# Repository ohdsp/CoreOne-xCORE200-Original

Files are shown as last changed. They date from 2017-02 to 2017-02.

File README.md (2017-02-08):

# [Open Hardware DSP Platform](http://www.ohdsp.org)
## CoreOne
### Revision 1.0

---
# README
### Disclaimer
Copyright Paul Janicki 2017

Licensed under the TAPR Open Hardware License (www.tapr.org/OHL)

This documentation is distributed WITHOUT ANY EXPRESS OR IMPLIED WARRANTY, INCLUDING OF MERCHANTABILITY, SATISFACTORY QUALITY AND FITNESS FOR A PARTICULAR PURPOSE.

### What is this repository?

**Quick summary**

This is Open Hardware DSP Platform CoreOne Module. 

This is an XMOS 200 based DSP and microcontroller PCB design with USB, SPDIF, I2S/TDM, SPI, I2C, and Ethernet connectivity options.

This repository contains the KiCad design files, manufacturing Gerber/drill files, PDF/drawing files, and relevant documenation for this board.

### What is the project folder structure?
Most folder names are self explanatory. Starting from the top level: \
*CoreOne*
+ *Bill of Materials*  - This contains the bill of materials in CVS, LibreOffice Calc and XML formats
+ *Calculations*  - This contains calculations performed using SMath Studio 
+ *Drawings*  - This contains PDF and SVG outputs of schematic and PCB files
+ *Gerbers* - This contains the PCB Gerbers and drill drawings for manufacture, there is also a zip file ready to send to most manufacturers
+ *KiCad* - This contains the original KiCad schematic and PCB design files
+ *Pick and Place* - This contains the pick and place file for automated placement of PCB components

### How do I get set up?

**Summary of set up**

1. Set your self up a directory on a local disk, something simple will make life easier (eg C:\Electronics on Windows as used here), but anywhere will do just fine.
2. Download the Kicad-Libs from [https://github.com/ohdsp/KiCad-Libs](https://github.com/ohdsp/KiCad-Libs) and place in C:\Electronics\Kicad-Libs (or your chosen folder) 
3. Create a OHDSP subdirectory in C:\Electronics (so C:\Electronics\OHDSP)
3. Download this project to C:\Electronics\OHDSP\CoreOne
4. Fire up Kicad
5. Open the main project file C:\Electronics\OHDSP\CoreOne\KiCad\CoreOne.pro
6. (Optional) Setup Pcbnew component library as below.
7. Do as you wish with the project, just keep it under TAPR Open Hardware License

Make sure your git setup doesn't exclude files used in the project (like .LIB files) or things may go wrong down the line.

**KiCad Library Configuration**

Note that you need to setup a Pcbnew library, but the eeschema libraries should work without any changes if you followed the instructions above.

To setup Pcbnew libraries:

In Pcbnew go to Preferences -> Footprint Libraries Manager. Under Global Libraries tab in the top list check if there is a nickname "MyKiCadLibs-Footprints" (usually at the end of the list). If there is but it points to the wrong place then change the Library Path to point to MyKiCadLibs-Footprints (eg C:\Electronics\KiCad-Libs\MyKiCadLibs-Footprints.pretty) folder for your setup. If this is missing you can use "Append with Wizard", choose "Files on my computer", click next, browse to library location (eg C:\Electronics\KiCad-Libs\MyKiCadLibs-Footprints.pretty) and select the folder MyKiCadLibs-Footprints.pretty, click next, check the Status column states OK and the Format is KiCad (if not re-download the library) and click next, then select "To global library configuration..." and click Finish.

To setup eeschema component libraries:
Either from KiCad project window go to Tools -> Run Library Editor OR under eeschema, go to Tools -> Library Editor. Then Preferences -> Component Libraries.

The top section "Component Library Files" should ideally contain only two libraries, the "power" library that ships with KiCad and "MyKiCadLibs-Lib" available from above. To setup MyKiCadLibs-Lib as a relative path under the "User defined search path" click add. Browse to the location of KiCad-Libs you download above (eg C:\Electronics\KiCad-Libs) and click "Select Folder". Say yes to add a relative path. Under component library files click add, browse to the KiCad-libs again (eg C:\Electronics\KiCad-Libs), select file "MyKiCadLibs-Lib.lib" and click open. MyKiCadLibs-lib should appear in the component library list with no path as it will be using the user defined search path set in the box below.

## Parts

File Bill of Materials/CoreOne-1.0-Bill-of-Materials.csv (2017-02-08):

Reference | Quantity | Footprint | Value | Voltage | Type | Description | Tolerance | Size | Power | Current
C103 C105 C107 C218 C220 C221 C223 C305 C504 C644 C806 C807 C820 C858 C859 | 15 | SMD-0805 | 22u | '10V | 'X5R | 'Ceramic capacitor | '20% | '0805 | ' | '
C104 C106 C108 C203 C205 C206 C207 C208 C212 C224 C226 C231 C304 C306 C311 C312 C313 C315 C316 C404 C505 C508 C510 C512 C615 C617 C638 C641 C647 C653 C656 C703 C706 C707 C808 C852 C860 C861 | 38 | SMD-0805 | 100n | '50V | 'X7R | 'Ceramic capacitor | '10% | '0805 | ' | '
C201 C210 | 2 | CAP-TH-D6.3mmP2.5mm | 220u | '16V | '2.5mm pitch, 6.3mm diameter | 'Aluminium electrolytic capacitor | ' | ' | ' | '
C209 C301 C501 C637 C701 C802 C803 C816 C854 C855 | 10 | SMD-0805 | 100p | '50V | 'C0G | 'Ceramic capacitor | '5% | '0805 | ' | '
C202 C204 C211 | 3 | SMD-0805 | 22u | '25V | 'X5R | 'Ceramic capacitor | '20% | '0805 | ' | '
C214 C216 C709 | 3 | SMD-0805 | N/F | '50V | 'X7R | 'Ceramic capacitor | '10% | '0805 | ' | '
C227 C229 C303 C503 C640 C804 C805 C818 C856 C857 | 10 | CAP-TH-D6.3mmP2.5mm | 220u | '10V | '2.5mm pitch, 6.3mm diameter | 'Low impedance aluminium electrolytic capacitor - Panasonic FC, FR or similar | ' | ' | ' | '
C302 C309 C310 C507 C509 C511 C619 C702 C853 | 9 | SMD-0805 | 10u | '10V | 'X5R | 'Ceramic capacitor | '20% | '0805 | ' | '
C502 C506 C601 C602 | 4 | SMD-0805 | 33p | '50V | 'NP0 | 'Ceramic capacitor | '5% | '0805 | ' | '
C609 C611 | 2 | SMD-0805 | 1u | '10V | 'X7R | 'Ceramic capacitor | '10% | '0805 | ' | '
C704 C705 C708 C851 | 4 | SMD-0805 | 10n | '50V | 'X7R | 'Ceramic capacitor | '10% | '0805 | ' | '
C810 C812 C814 | 3 | SMD-0603 | 1u | '10V | 'X7R | 'Ceramic capacitor | '10% | '0603 | ' | '
C811 C824 C832 C834 C840 C844 C846 C850 C867 | 9 | SMD-0603 | 10n | '50V | 'X7R | 'Ceramic capacitor | '10% | '0603 | ' | '
C809 C823 C831 C833 C839 C843 C845 C849 C862 C863 C864 C866 C870 C871 C873 C874 | 16 | SMD-0603 | 100n | '50V | 'X7R | 'Ceramic capacitor | '10% | '0603 | ' | '
CN301 CN302 CN501 | 3 | CONN_SIL_2_1MM | COAX | ' | ' | '1x2 2.54mm pitch pin header - use with 75Ohm coax | ' | ' | ' | '
CN401 | 1 | CONN-USB-B-61729-0010 | CONN-USB-B-61729 | ' | ' | 'USB B Connector - Amphenol 61729 Series - eg: 61729-0010 | ' | ' | ' | '
CN601 | 1 | CONN-RJ45-ARJC02-111xxxx | CONN_RJ45_ARJC02-111xxxx | ' | ' | 'Amphenol RJE48 series RJ45 connector with LED - eg: RJE48-188-1411 | ' | ' | ' | '
D201 | 1 | DIODE-SMA | B240A | ' | ' | 'B240A 2A 40V Schottky Rectifier - SMA (DO-214AC) | ' | ' | ' | '
D202 | 1 | SMD-1206 | Green LED 1206 | ' | ' | 'Green LED - SMD - Vf 1.8V to 2.2V | ' | '1206 | ' | '
D401 D402 D403 D404 D405 D406 D407 D408 | 8 | IC-SOT23 | BAV99 | ' | ' | 'Text description | ' | ' | ' | '
D601 D602 | 2 | DIODE-SOD-123 | SS14L | ' | ' | 'SS14L 1A 40V Schottky rectifier - Sub-SMA (SOD-123) | ' | ' | ' | '
FID201 FID202 FID203 | 3 | FID-1MM-3MM | MNT_HOLE | ' | ' | 'Fiducial | ' | ' | ' | '
JP301 | 1 | CONN_SIL_3_1MM | CONN_3x1 | ' | ' | '1x3 2.54mm pitch pin header | ' | ' | ' | '
L201 L301 L501 L604 L801 L802 L803 L804 L805 | 9 | SMD-0805 | 600R@100MHz | ' | ' | 'Ferrite bead, current rating 1A or higher, 600R@100MHz | ' | '0805 | ' | '=>1A
L202 | 1 | IND-TH-DR0608 | DR0608-332L | ' | ' | 'Coilcraft DR0608-332L DCR=0.012Ohm Isat=5.3A Irms=5.0A | ' | ' | ' | '2.7A
L204 | 1 | IND-TH-DR0608 | DR0608-153L | ' | ' | 'Coilcraft DR0608-153L DCR=0.052Ohm Isat=2.7A Irms=2.7A | ' | ' | ' | '2.7A
MNT201 MNT202 MNT203 MNT204 | 4 | MNT_HOLE_3.2mm | MNT_HOLE | ' | ' | 'Mounting hole | ' | ' | ' | '
P201 | 1 | CONN-2WAY-2.54mm-3.81mm-SPACING | CONN_2x1 | ' | ' | '2 way screw terminal, any 2.54mm to 3.81mm pitch part | ' | ' | ' | '
JP801 JP802 JP803 JP804 P202 P701 | 6 | CONN_SIL_2_1MM | CONN_2x1 | ' | ' | '1x2 2.54mm pitch pin header | ' | ' | ' | '
P402 P408 | 2 | CONN_DIL_2X04 | CONN_02X04 | ' | ' | '2x4 2.54mm pitch pin header | ' | ' | ' | '
P403 | 1 | CONN_DIL_2X10_BOX_1MM | CONN_02X10 | ' | ' | '2x10 2.54mm pitch box header | ' | ' | ' | '
P404 | 1 | CONN_DIL_2X4_BOX_1MM | CONN_02X04 | ' | ' | '2x4 2.54mm pitch box header | ' | ' | ' | '
P405 | 1 | CONN_DIL_2X6_BOX_1MM | CONN_02X06 | ' | ' | '2x6 2.54mm pitch box header | ' | ' | ' | '
P401 P406 P407 | 3 | CONN_DIL_2X5_BOX_1MM | CONN_02X05 | ' | ' | '2x5 2.54mm pitch box header | ' | ' | ' | '
R101 R102 R104 R106 R108 R208 R214 R413 R414 R416 R417 R418 R420 R421 R422 R427 R429 R713 R821 R822 R823 R824 R825 R826 R827 R828 R829 R830 R831 R862 R874 R875 R887 R888 R890 R891 R892 R893 | 38 | SMD-0805 | 0 | ' | ' | 'Thick or thin film resistor | '1% | '0805 | '100mW | '
R103 R105 R107 R109 R401 R402 R409 R410 R423 R424 R425 R426 R434 R435 R436 R438 R504 R506 R510 R515 R602 R620 R631 R633 R638 R642 R803 R804 | 28 | SMD-0805 | N/F | ' | ' | 'Thick or thin film resistor | '1% | '0805 | '100mW | '
R110 R111 R112 R113 R114 R115 R116 R117 R604 R605 R606 R607 R608 R609 R621 R863 R864 R869 R877 R878 R879 R880 R881 R883 R884 R885 R886 R889 | 28 | SMD-0805 | 33 | ' | ' | 'Thick or thin film resistor | '1% | '0805 | '100mW | '
R201 R204 R403 R404 R405 R406 R407 R408 R412 R415 R502 R511 R610 R611 R613 R619 R632 R634 R805 R806 R820 R843 | 22 | SMD-0805 | 1k | ' | ' | 'Thick or thin film resistor | '1% | '0805 | '100mW | '
R202 R209 | 2 | SMD-0805 | 10 | ' | ' | 'Thick or thin film resistor | '1% | '0805 | '100mW | '
R203 | 1 | SMD-0805 | 750 | ' | ' | 'Thick or thin film resistor | '1% | '0805 | '100mW | '
R205 R301 R501 R617 R702 R801 R802 R817 R865 R866 | 10 | SMD-0805 | 47 | ' | ' | 'Thick or thin film resistor | '1% | '0805 | '100mW | '
R206 | 1 | SMD-0805 | 8k25 | ' | ' | 'Thick or thin film resistor | '1% | '0805 | '100mW | '
R207 | 1 | SMD-0805 | 33k | ' | ' | 'Thick or thin film resistor | '1% | '0805 | '100mW | '
R212 | 1 | SMD-0805 | 36k | ' | ' | 'Thick or thin film resistor | '1% | '0805 | '100mW | '
R213 | 1 | SMD-0805 | 11k5 | ' | ' | 'Thick or thin film resistor | '1% | '0805 | '100mW | '
R215 | 1 | SMD-0805 | 220 | ' | ' | 'Thick or thin film resistor | '1% | '0805 | '100mW | '
R304 R305 R306 R307 R313 R430 R431 R432 | 8 | SMD-0805 | 75 | ' | ' | 'Thick or thin film resistor | '1% | '0805 | '100mW | '
R302 R308 R309 R612 R703 R844 | 6 | SMD-0805 | 10k | ' | ' | 'Thick or thin film resistor | '1% | '0805 | '100mW | '
R310 | 1 | SMD-0805 | 360 | ' | ' | 'Thick or thin film resistor | '1% | '0805 | '100mW | '
R311 R709 R710 R711 | 4 | SMD-0805 | 100 | ' | ' | 'Thick or thin film resistor | '1% | '0805 | '100mW | '
R312 | 1 | SMD-0805 | 91 | ' | ' | 'Thick or thin film resistor | '1% | '0805 | '100mW | '
R411 R701 | 2 | SMD-0805 | 1 | ' | ' | 'Thick or thin film resistor | '1% | '0805 | '100mW | '
R503 | 1 | SMD-0805 | 1Meg | ' | ' | 'Thick or thin film resistor | '1% | '0805 | '100mW | '
R507 R512 | 2 | SMD-0805 | 0R | ' | ' | 'Thick or thin film resistor | '1% | '0805 | '100mW | '
R505 R508 R509 R513 R516 | 5 | SMD-0805 | 33R | ' | ' | 'Thick or thin film resistor | '1% | '0805 | '100mW | '
R615 | 1 | SMD-0805 | 6K49 | ' | ' | 'Thick or thin film resistor | '1% | '0805 | '100mW | '
R623 R624 | 2 | SMD_MELF_0207 | 220 | ' | ' | 'MELF Resistor | '1% | 'MELF0207 | '400mW | '
R637 R641 | 2 | SMD-0805 | 4k7 | ' | ' | 'Thick or thin film resistor | '1% | '0805 | '100mW | '
R708 | 1 | SMD-0805 | 7k5 | ' | ' | 'Thick or thin film resistor | '1% | '0805 | '100mW | '
R704 R712 | 2 | SMD-0805 | 100k | ' | ' | 'Thick or thin film resistor | '1% | '0805 | '100mW | '
R818 R819 | 2 | SMD-0805 | 2k2 | ' | ' | 'Thick or thin film resistor | '1% | '0805 | '100mW | '
R876 | 1 | SMD-0805 | 43R2 | ' | ' | 'Thick or thin film resistor | '1% | '0805 | '100mW | '
SW701 | 1 | SW_TACT_SMD | SWITCH | ' | ' | '6mm x 6mm SMD tactile switch - e.g. TE FSM2JSMA | ' | ' | ' | '
TP401 TP402 TP403 TP404 TP405 TP406 TP407 TP408 TP411 TP412 TP413 TP414 TP415 TP416 | 14 | TP-TH-1mm | PIN
TP501 | 1 | TP-1mm | PIN
TP803 | 1 | TP-1mm | PIN | ' | ' | 'Text description | ' | ' | ' | '
U102 U103 U104 | 3 | IC-SC70-6 | NC7WZ16P6X
U201 U202 | 2 | IC_SOIC_8 | IC-REG-ST1S40IDR | ' | ' | 'ST ST1S31 SO8 3 A DC step-down switching regulator | ' | ' | ' | '
U301 | 1 | IC-SC70-6 | NC7WZ16P6X | ' | ' | 'UHS Dual Buffer | ' | ' | ' | '
U302 | 1 | IC_SPDIF_OPTO | IC-SPDIF-RX-OPTO | ' | ' | 'TOSLINK receiver e.g. CLIFF FC684205R | ' | ' | ' | '
U303 | 1 | IC_SPDIF_OPTO | IC-SPDIF-TX-OPTO | ' | ' | 'TOSLINK transmitter e.g. CLIFF FC684205T | ' | ' | ' | '
U304 | 1 | IC_SOIC_14 | 74HC04 | ' | ' | '74HC04 Hex Inverter - SOIC-14 | ' | ' | ' | '
U501 | 1 | IC-SC70-6 | NC7WZ04P6X | ' | ' | 'NC7WZ04 TinyLogic UHS Dual Inverter | ' | ' | ' | '
U502 | 1 | IC-MSOP-10 | CS2200-CP | ' | ' | 'Cirrus Logic CS2200-CP Fractional-N Frequency Synthesizer | ' | ' | ' | '
U503 | 1 | IC-MSOP-10 | CS2100-CP | ' | ' | 'Cirrus Logic CS2100-CP Fractional-N Frequency Synthesizer | ' | ' | ' | '
U601 | 1 | IC-LQFP48_7x7 | KSZ8081MLX | ' | ' | 'Microchip KSZ8081MLXCA LQFP-48 10Base-T/100Base-TX Ethernet PHY | ' | ' | ' | '
U701 | 1 | IC-SOT23-6 | TPS3808 | ' | ' | 'TI TPS3808 SOT-23 Reset Supervisor | ' | ' | ' | '
U801 | 1 | IC-TQ128-XMOS-HF | IC-uC-XE216-512-TQ128 | ' | ' | 'XMOS 200 XE216-512-TQ128 Microcontroller | ' | ' | ' | '
U802 | 1 | IC_SOIC_8 | IC-FLASH-SPI | ' | ' | 'SPI/Quad SPI Flash Memory - SOIC 8 - For use with XE-216-TQ128, XEF216-512-TQ128 has internal flash | ' | ' | ' | '
X501 | 1 | XTAL_HC49_TH | 24M000 | ' | ' | 'HC49 24.000MHz Crystal – 30ppm or better – 18pF | ' | ' | ' | '
X601 | 1 | XTAL_HC49_TH | 25M000 | ' | ' | 'HC49 25.000MHz Crystal – 50ppm or better – 18pF | ' | ' | ' | '

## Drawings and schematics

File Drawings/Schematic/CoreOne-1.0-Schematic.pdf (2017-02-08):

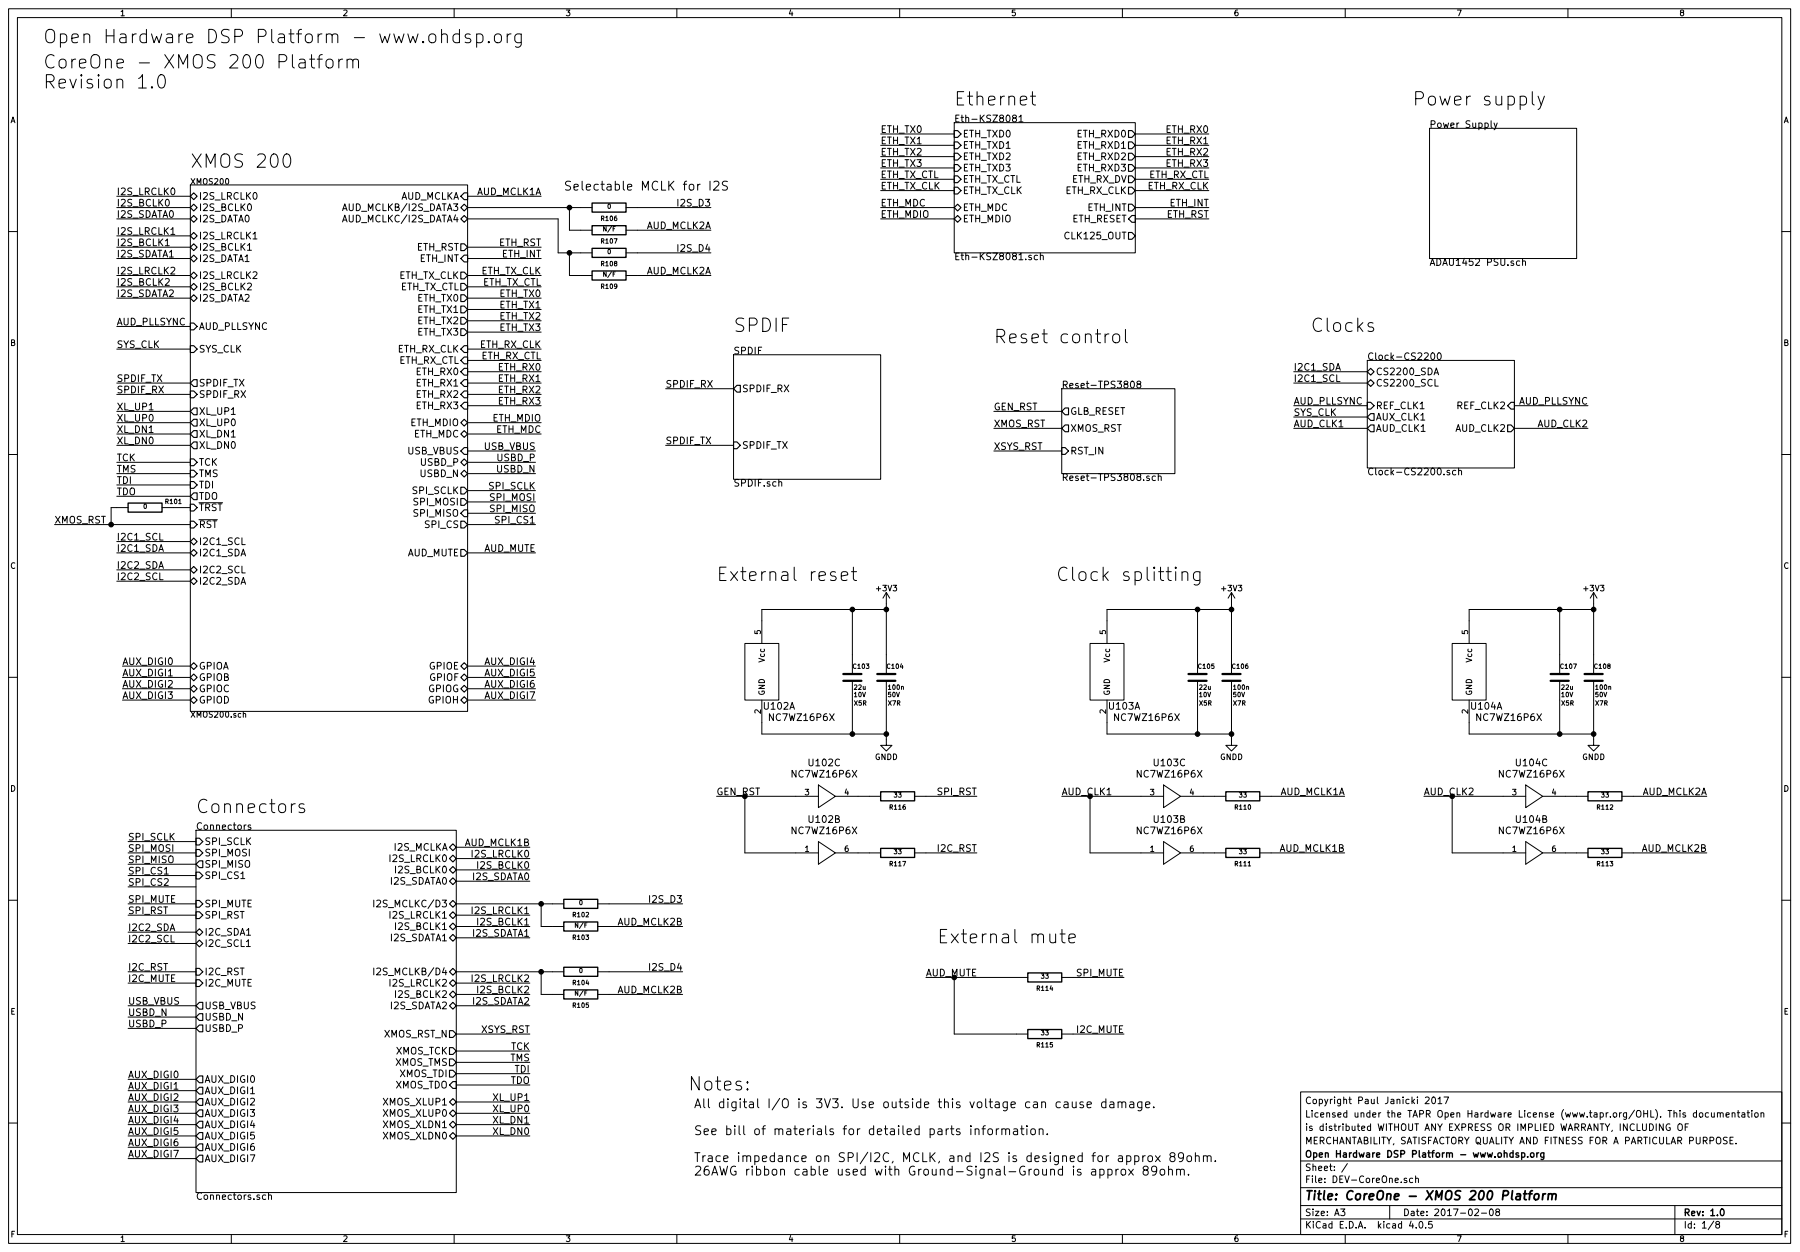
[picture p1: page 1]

Open Hardware DSP Platform - www.ohdsp.org
CoreOne - XMOS 200 Platform
Revision 1.0

ETH_TX1 | ETH_RX1
ETH_TX2 | ETH_RX2
ETH_TX3 | ETH_RX3
ETH_TX_CTL | | ETH_RX_CTL
ETH_TX_CLK | | ETH_RX_CLK

I2S_BCLK1
I2S_SDATA1 | ETH_INT

I2S_BCLK2 | ETH_TX_CTL
I2S_SDATA2

I2S_LRCLK1
I2S_SDATA1

I2C2_SCL

I2C_MUTE | | I2S_LRCLK2

I2S_BCLK2

Notes:
All digital I/O is 3V3. Use outside this voltage can cause damage.
See bill of materials for detailed parts information.
Trace impedance on SPI/I2C, MCLK, and I2S is designed for approx 89ohm.
26AWG ribbon cable used with Ground-Signal-Ground is approx 89ohm.

Copyright Paul Janicki 2017
Licensed under the TAPR Open Hardware License (www.tapr.org/OHL). This documentation
is distributed WITHOUT ANY EXPRESS OR IMPLIED WARRANTY, INCLUDING OF
MERCHANTABILITY, SATISFACTORY QUALITY AND FITNESS FOR A PARTICULAR PURPOSE.
File: DEV-CoreOne.sch Sheet: / Open Hardware DSP Platform - www.ohdsp.org

Id: 1/8 Title: CoreOne - XMOS 200 Platform

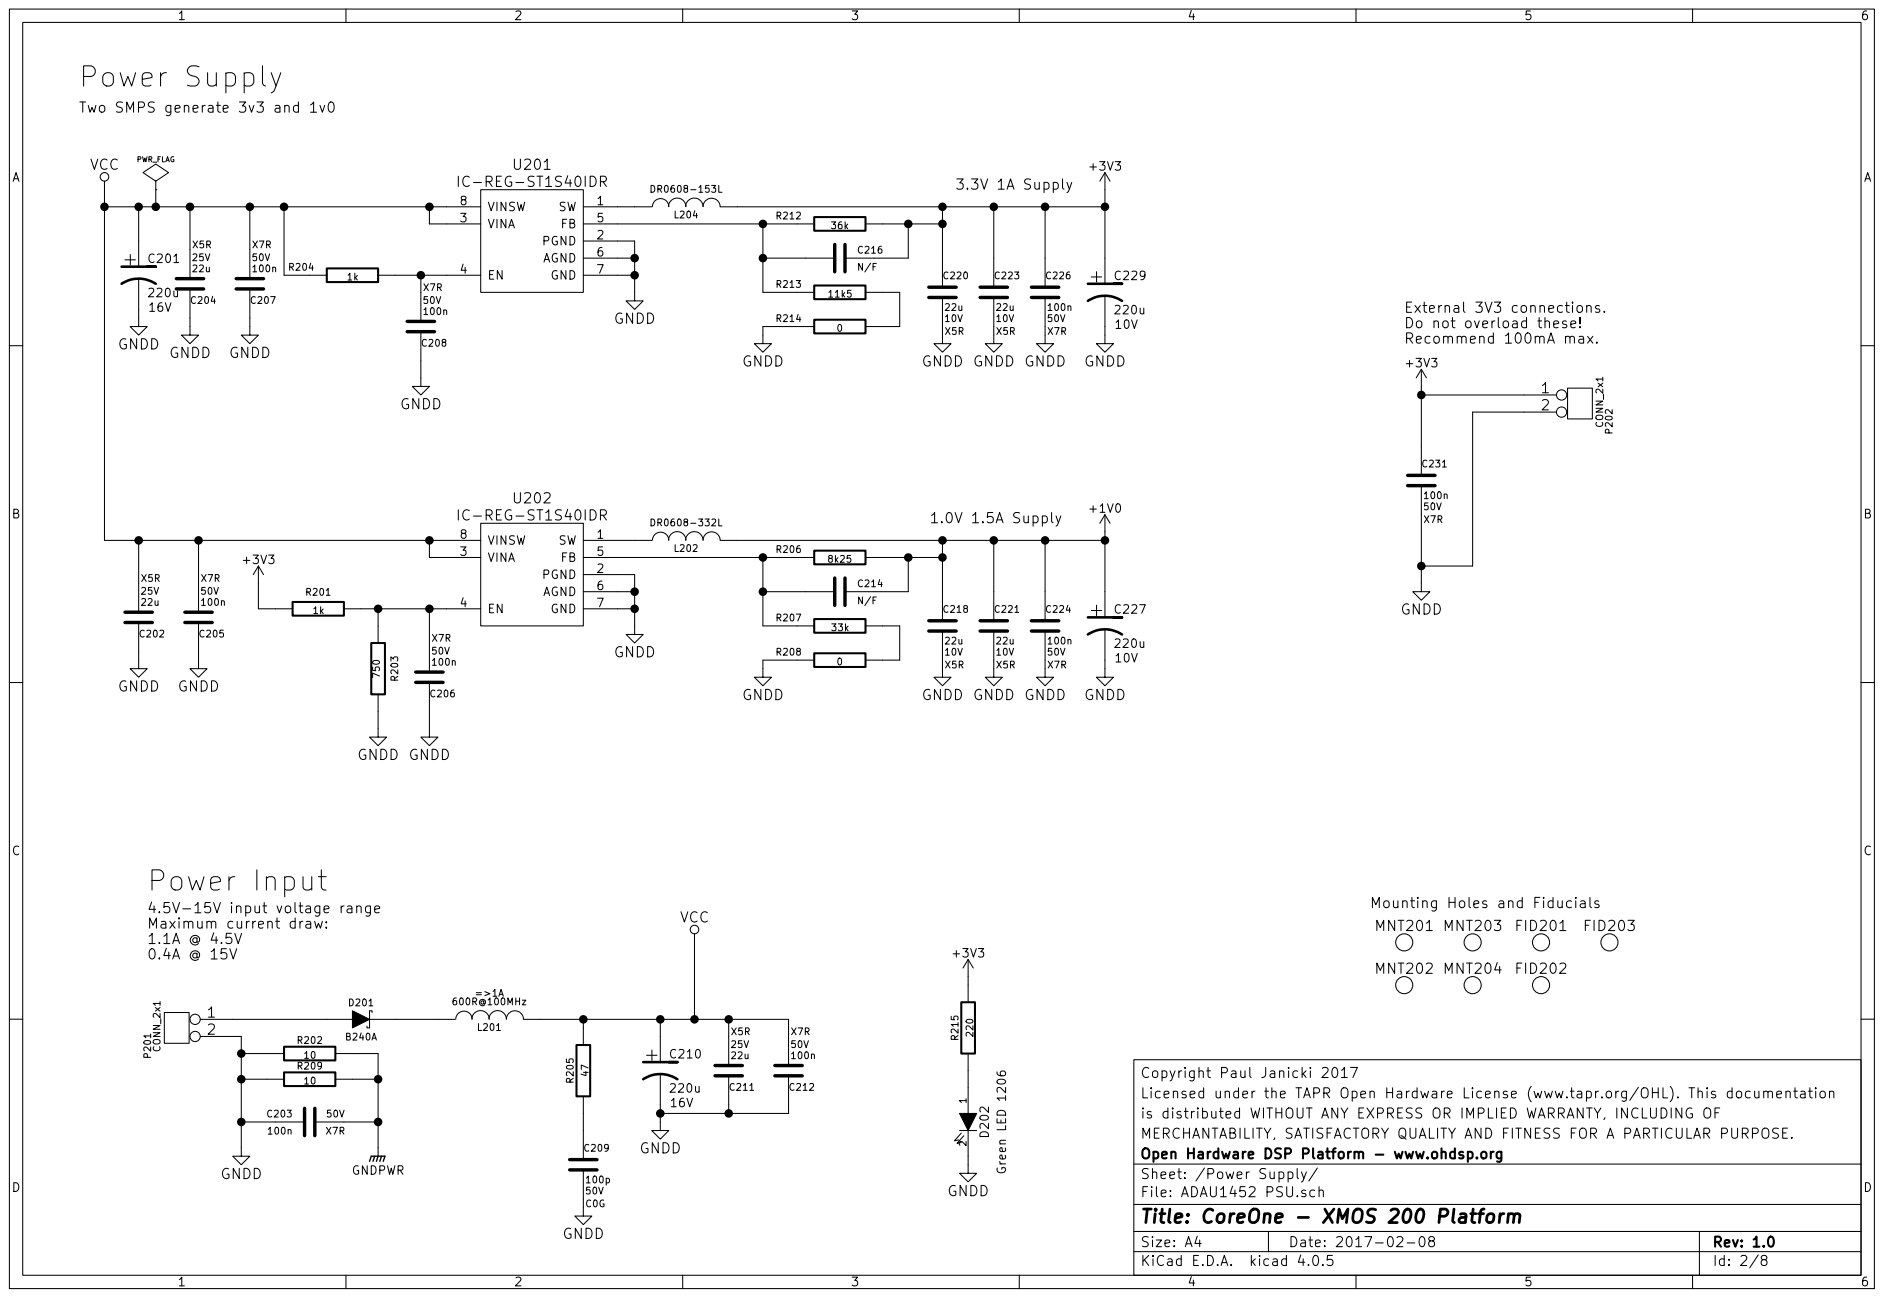
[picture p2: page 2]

Two SMPS generate 3v3 and 1v0

4.5V-15V input voltage range Maximum current draw: 1.1A @ 4.5V

Copyright Paul Janicki 2017
Licensed under the TAPR Open Hardware License (www.tapr.org/OHL). This documentation
is distributed WITHOUT ANY EXPRESS OR IMPLIED WARRANTY, INCLUDING OF
MERCHANTABILITY, SATISFACTORY QUALITY AND FITNESS FOR A PARTICULAR PURPOSE.
Open Hardware DSP Platform - www.ohdsp.org
File: ADAU1452 PSU.sch Sheet: /Power Supply/
Id: 2/8 Title: CoreOne - XMOS 200 Platform

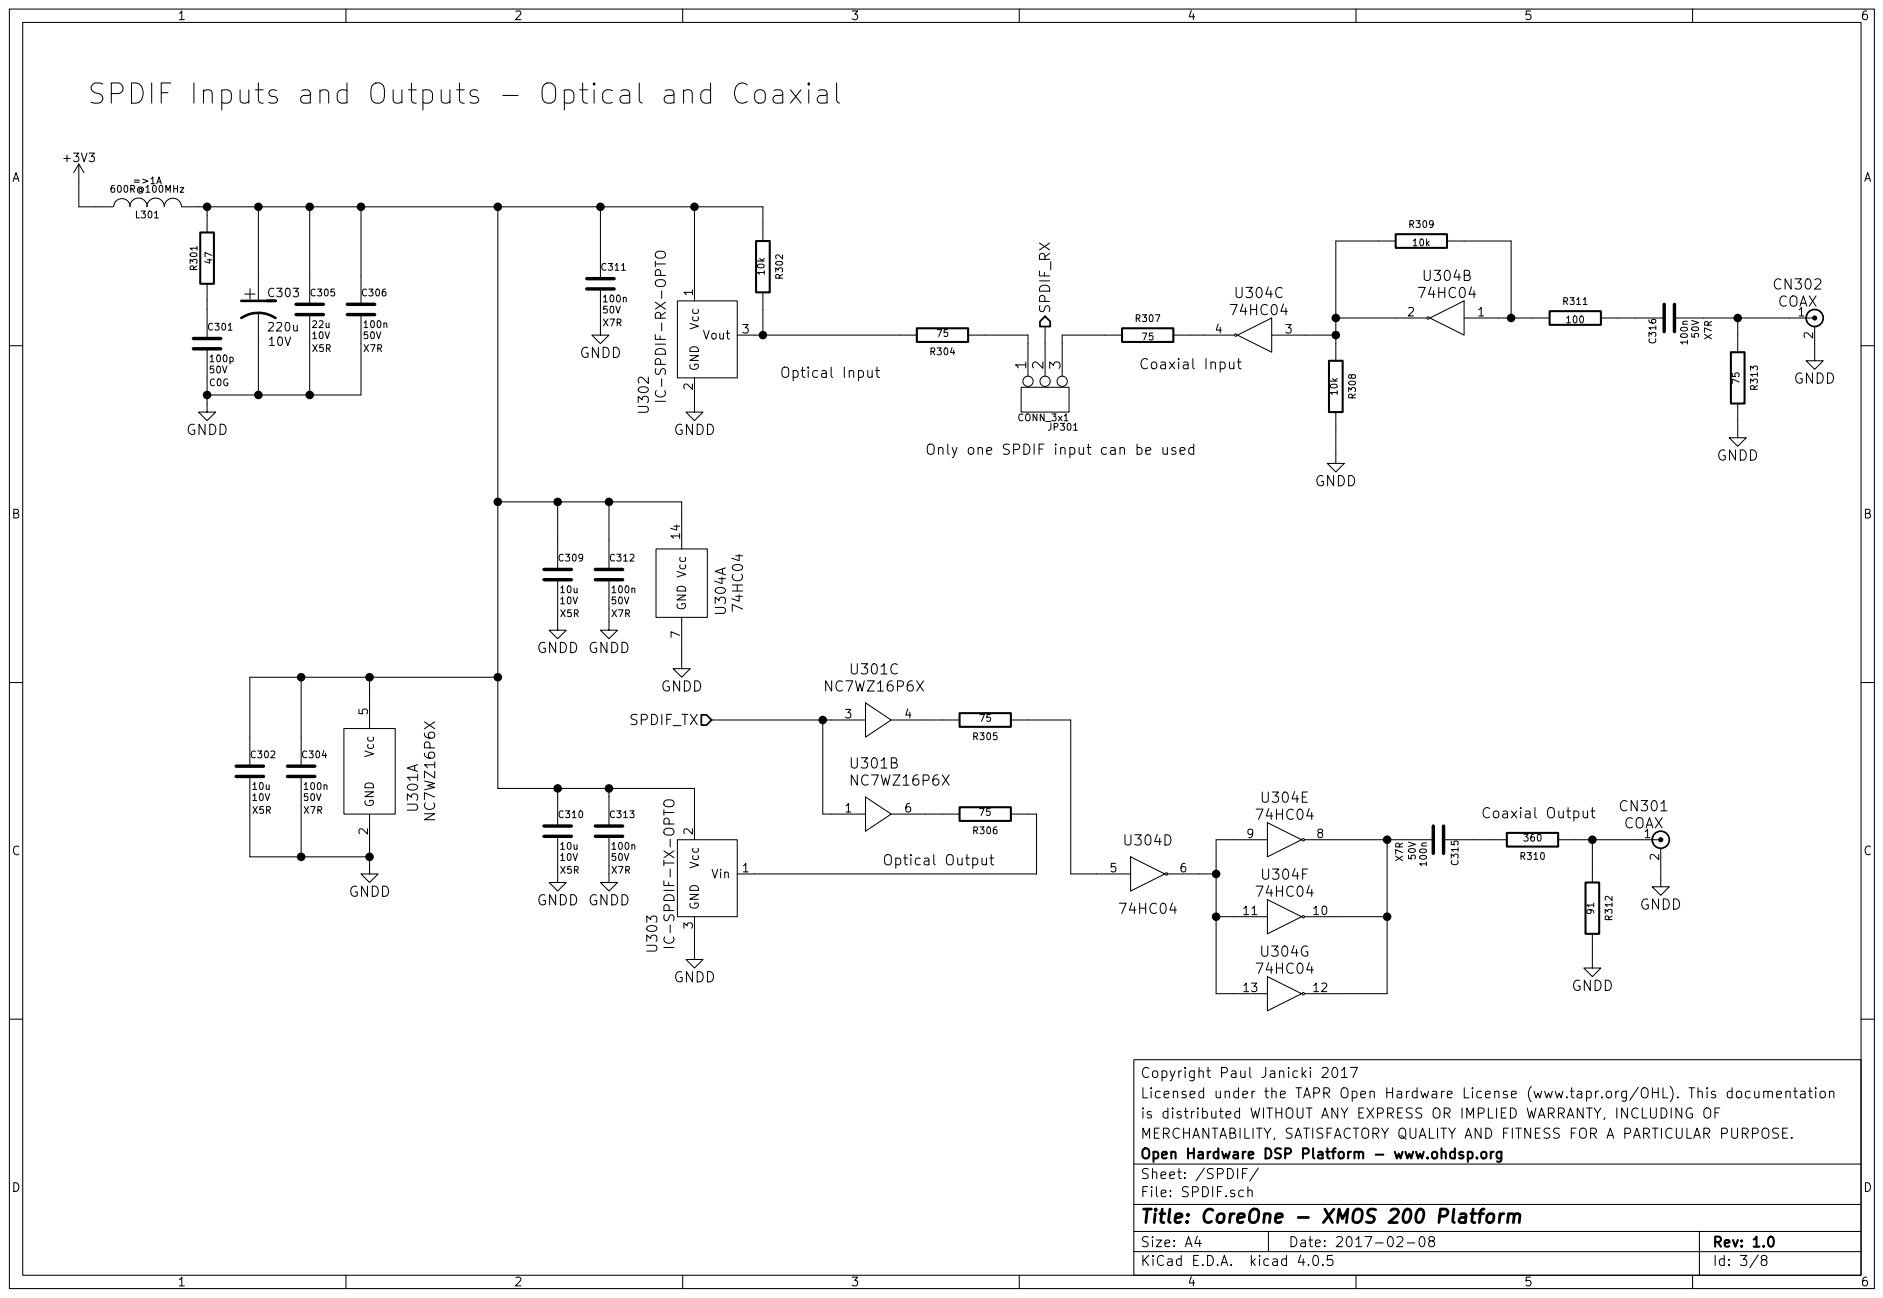
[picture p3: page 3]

SPDIF Inputs and Outputs - Optical and Coaxial Vcc 1 GND

2 Vout 3 U302IC-SPDIF-RX-OPTO

3 U303 IC-SPDIF-TX-OPTO

Copyright Paul Janicki 2017
Licensed under the TAPR Open Hardware License (www.tapr.org/OHL). This documentation
is distributed WITHOUT ANY EXPRESS OR IMPLIED WARRANTY, INCLUDING OF
MERCHANTABILITY, SATISFACTORY QUALITY AND FITNESS FOR A PARTICULAR PURPOSE.
File: SPDIF.sch Sheet: /SPDIF/ Open Hardware DSP Platform - www.ohdsp.org

Id: 3/8 Title: CoreOne - XMOS 200 Platform

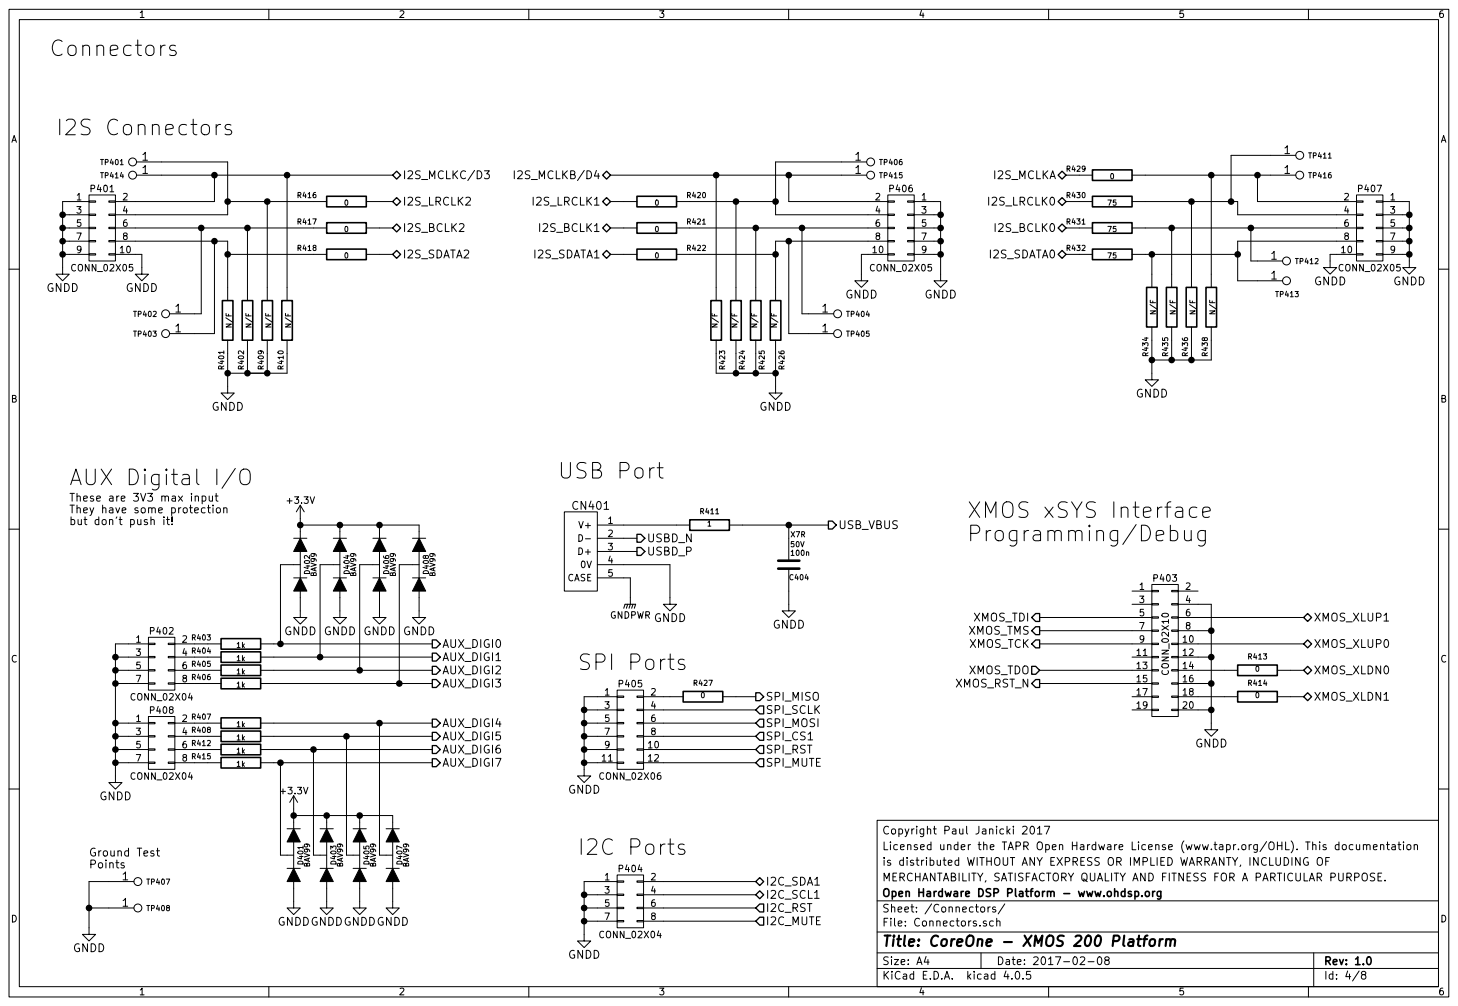
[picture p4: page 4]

These are 3V3 max input
They have some protection
but don't push it!

7 3 | 8 P402 CONN_02X04 4

Copyright Paul Janicki 2017

Licensed under the TAPR Open Hardware License (www.tapr.org/OHL). This documentation
is distributed WITHOUT ANY EXPRESS OR IMPLIED WARRANTY, INCLUDING OF
MERCHANTABILITY, SATISFACTORY QUALITY AND FITNESS FOR A PARTICULAR PURPOSE.
File: Connectors.sch Sheet: /Connectors/ Open Hardware DSP Platform - www.ohdsp.org

Id: 4/8 Title: CoreOne - XMOS 200 Platform

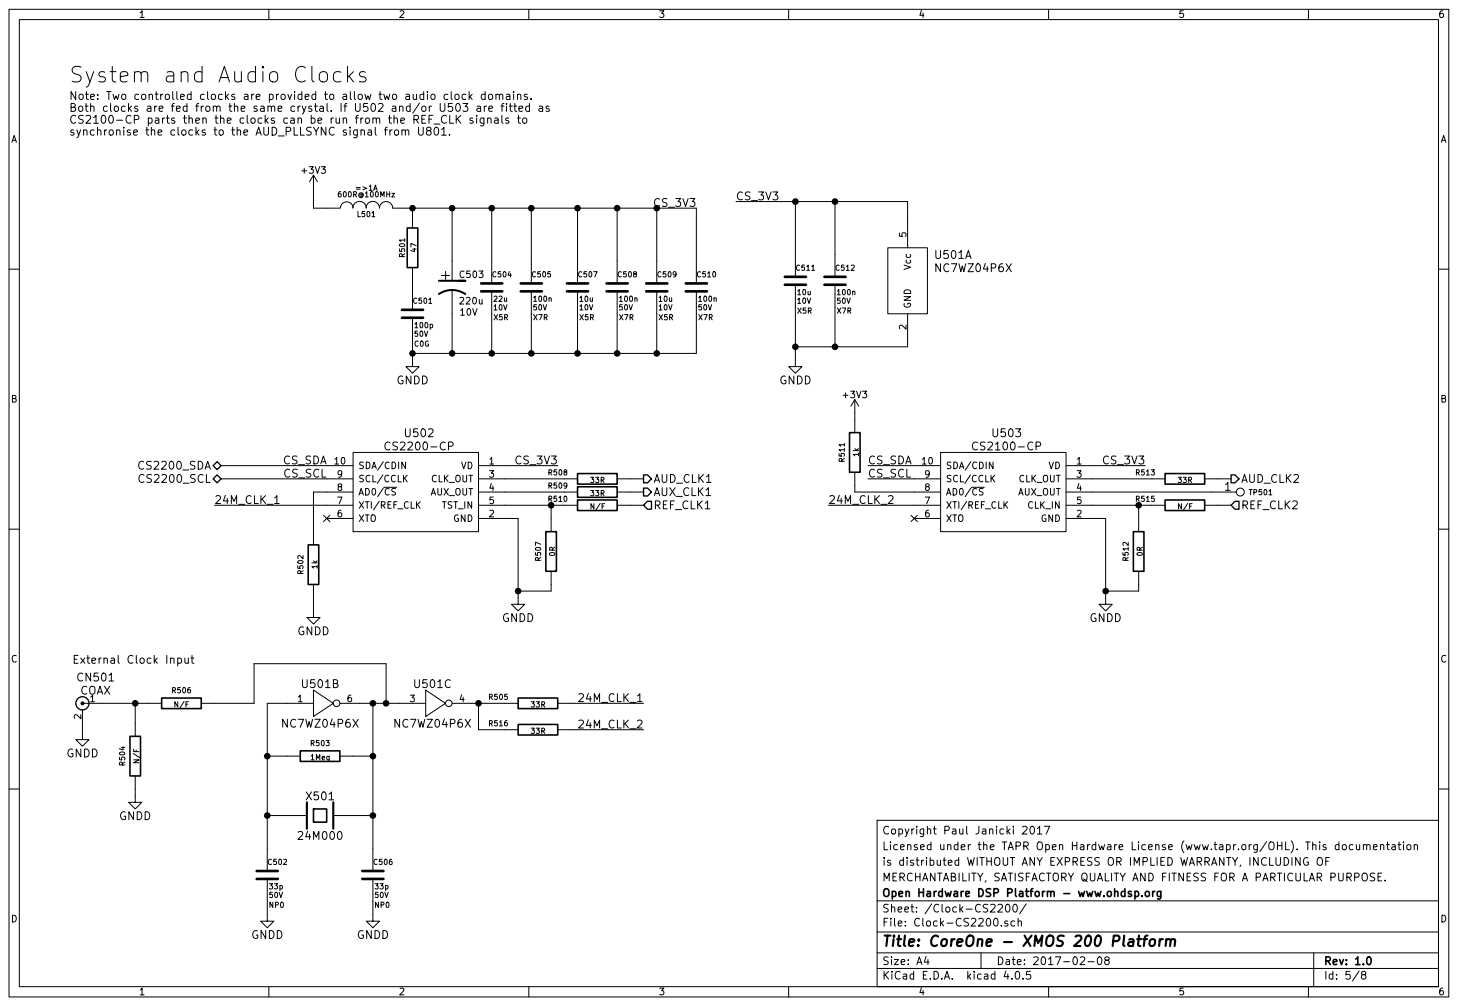
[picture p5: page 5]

System and Audio Clocks

Both clocks are fed from the same crystal. If U502 and/or U503 are fitted as
CS2100-CP parts then the clocks can be run from the REF_CLK signals to
synchronise the clocks to the AUD_PLLSYNC signal from U801.

Copyright Paul Janicki 2017
Licensed under the TAPR Open Hardware License (www.tapr.org/OHL). This documentation
is distributed WITHOUT ANY EXPRESS OR IMPLIED WARRANTY, INCLUDING OF
MERCHANTABILITY, SATISFACTORY QUALITY AND FITNESS FOR A PARTICULAR PURPOSE.
File: Clock-CS2200.sch Sheet: /Clock-CS2200/ Open Hardware DSP Platform - www.ohdsp.org

Id: 5/8 Title: CoreOne - XMOS 200 Platform

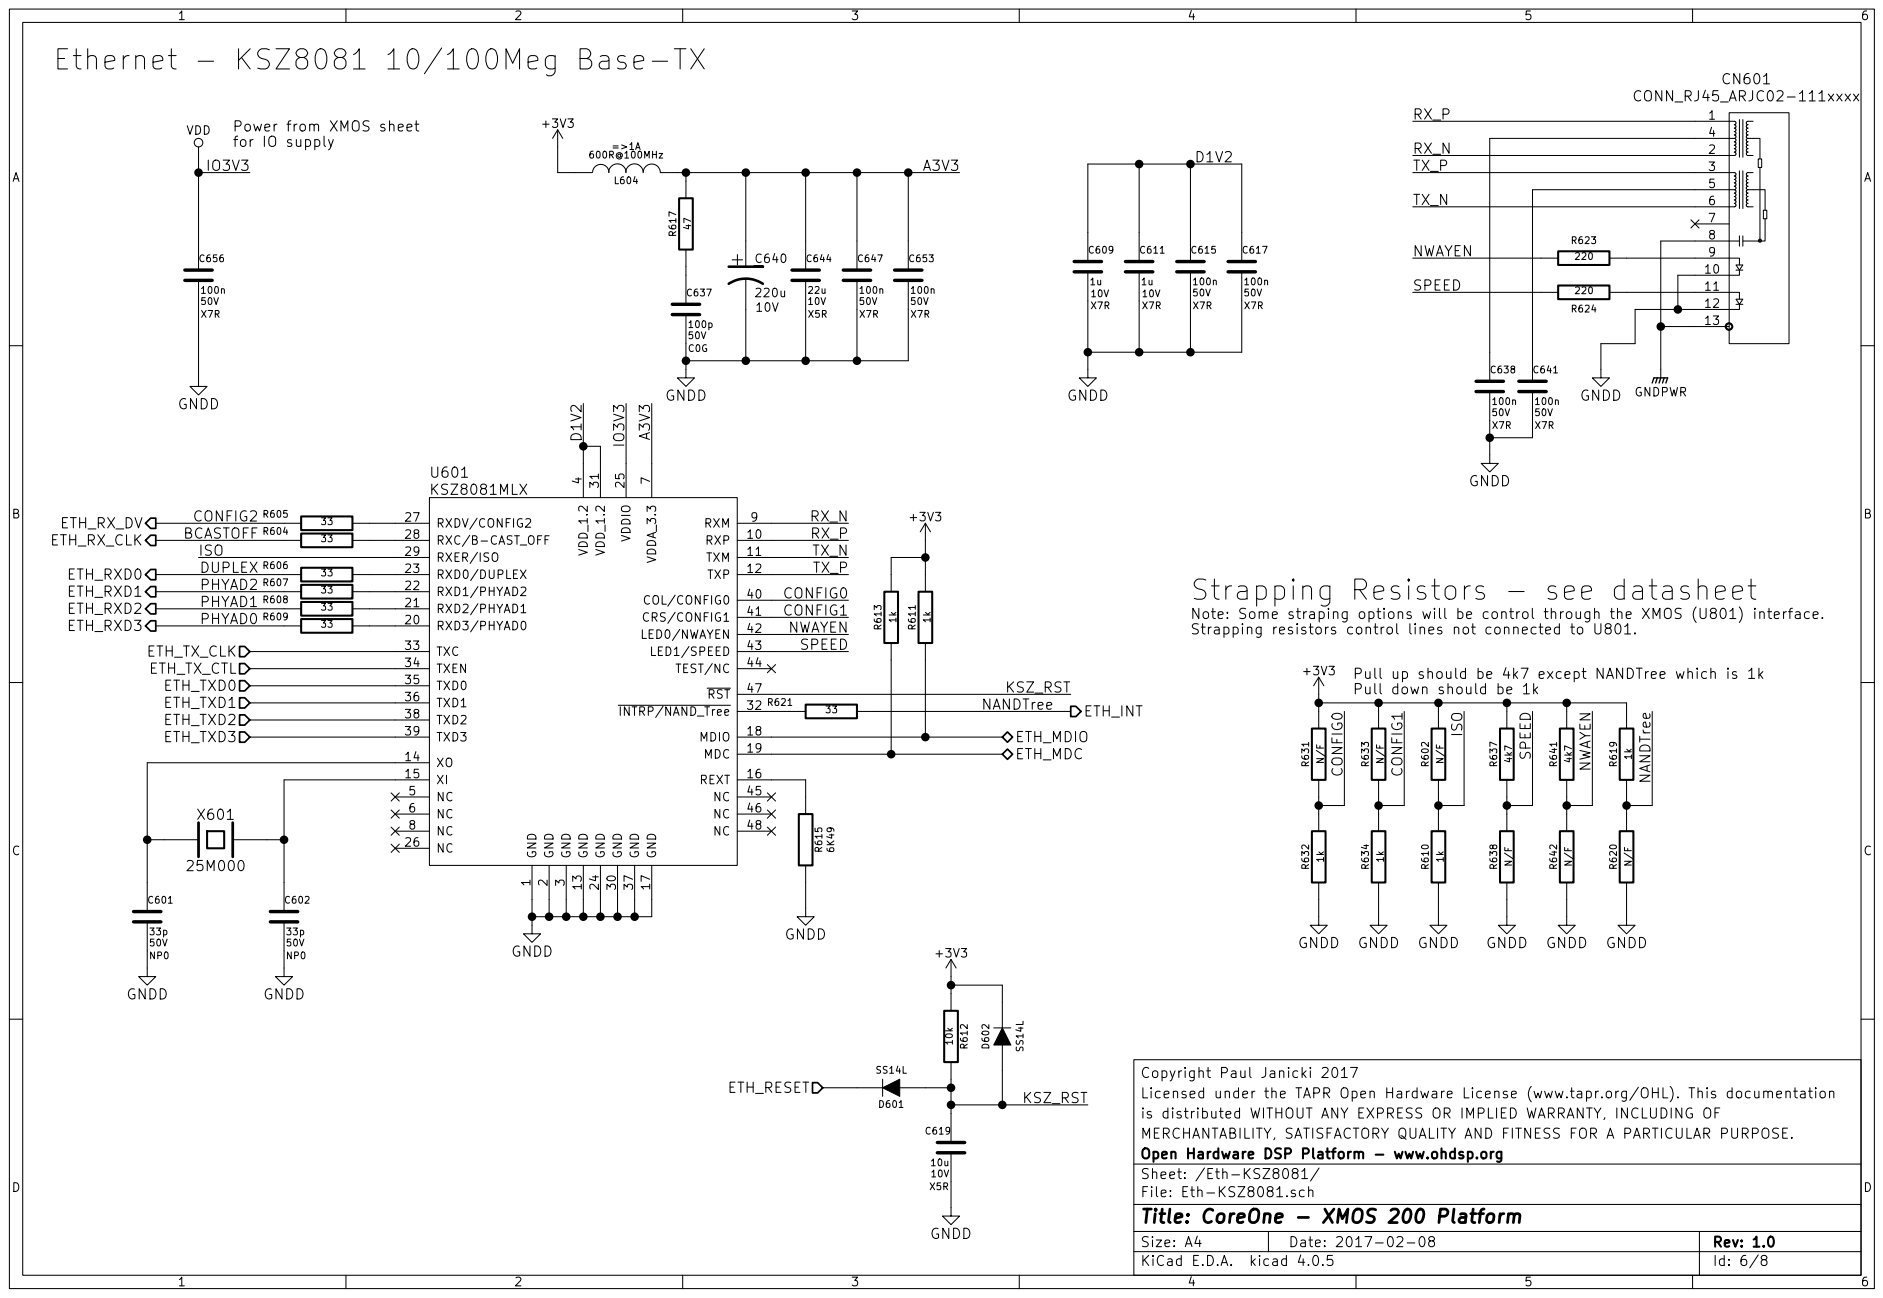
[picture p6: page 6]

7 NC 8 RXM 9 RXP 10 RXD3/PHYAD0 20 GND 30 COL/CONFIG0 40 TXM 11 RXD2/PHYAD1 21 VDD_1.2 31 CRS/CONFIG1 41 TXP 12 RXD1/PHYAD2 22

Note: Some straping options will be control through the XMOS (U801) interface.

Strapping resistors control lines not connected to U801. C619

Pull up should be 4k7 except NANDTree which is 1k Pull down should be 1k

Copyright Paul Janicki 2017
Licensed under the TAPR Open Hardware License (www.tapr.org/OHL). This documentation
is distributed WITHOUT ANY EXPRESS OR IMPLIED WARRANTY, INCLUDING OF
MERCHANTABILITY, SATISFACTORY QUALITY AND FITNESS FOR A PARTICULAR PURPOSE.
File: Eth-KSZ8081.sch Sheet: /Eth-KSZ8081/ Open Hardware DSP Platform - www.ohdsp.org

Id: 6/8 Title: CoreOne - XMOS 200 Platform

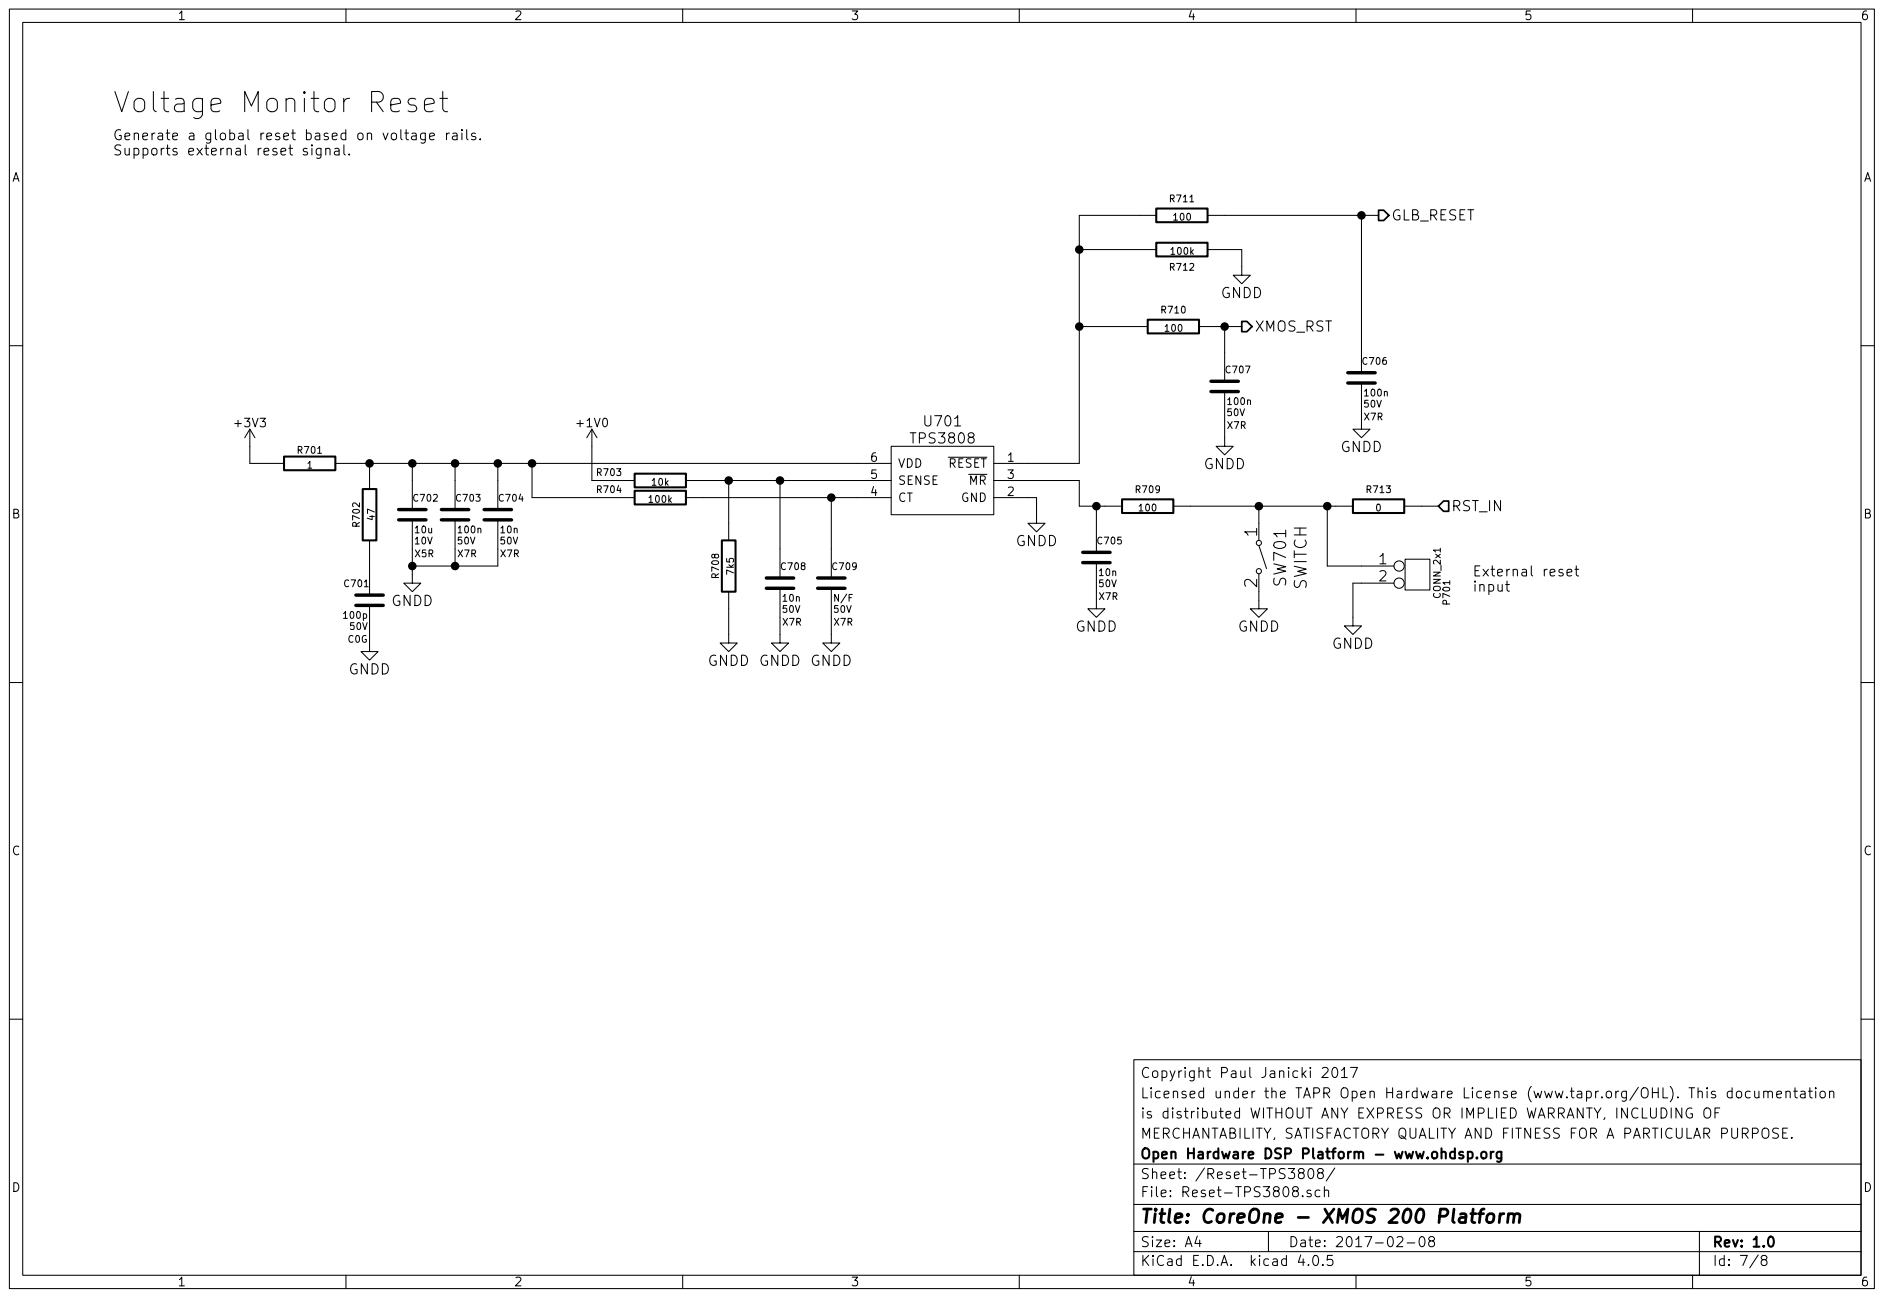
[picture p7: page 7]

Generate a global reset based on voltage rails.
Supports external reset signal.

Copyright Paul Janicki 2017
Licensed under the TAPR Open Hardware License (www.tapr.org/OHL). This documentation
is distributed WITHOUT ANY EXPRESS OR IMPLIED WARRANTY, INCLUDING OF
MERCHANTABILITY, SATISFACTORY QUALITY AND FITNESS FOR A PARTICULAR PURPOSE.
File: Reset-TPS3808.sch Sheet: /Reset-TPS3808/ Open Hardware DSP Platform - www.ohdsp.org

Id: 7/8 Title: CoreOne - XMOS 200 Platform

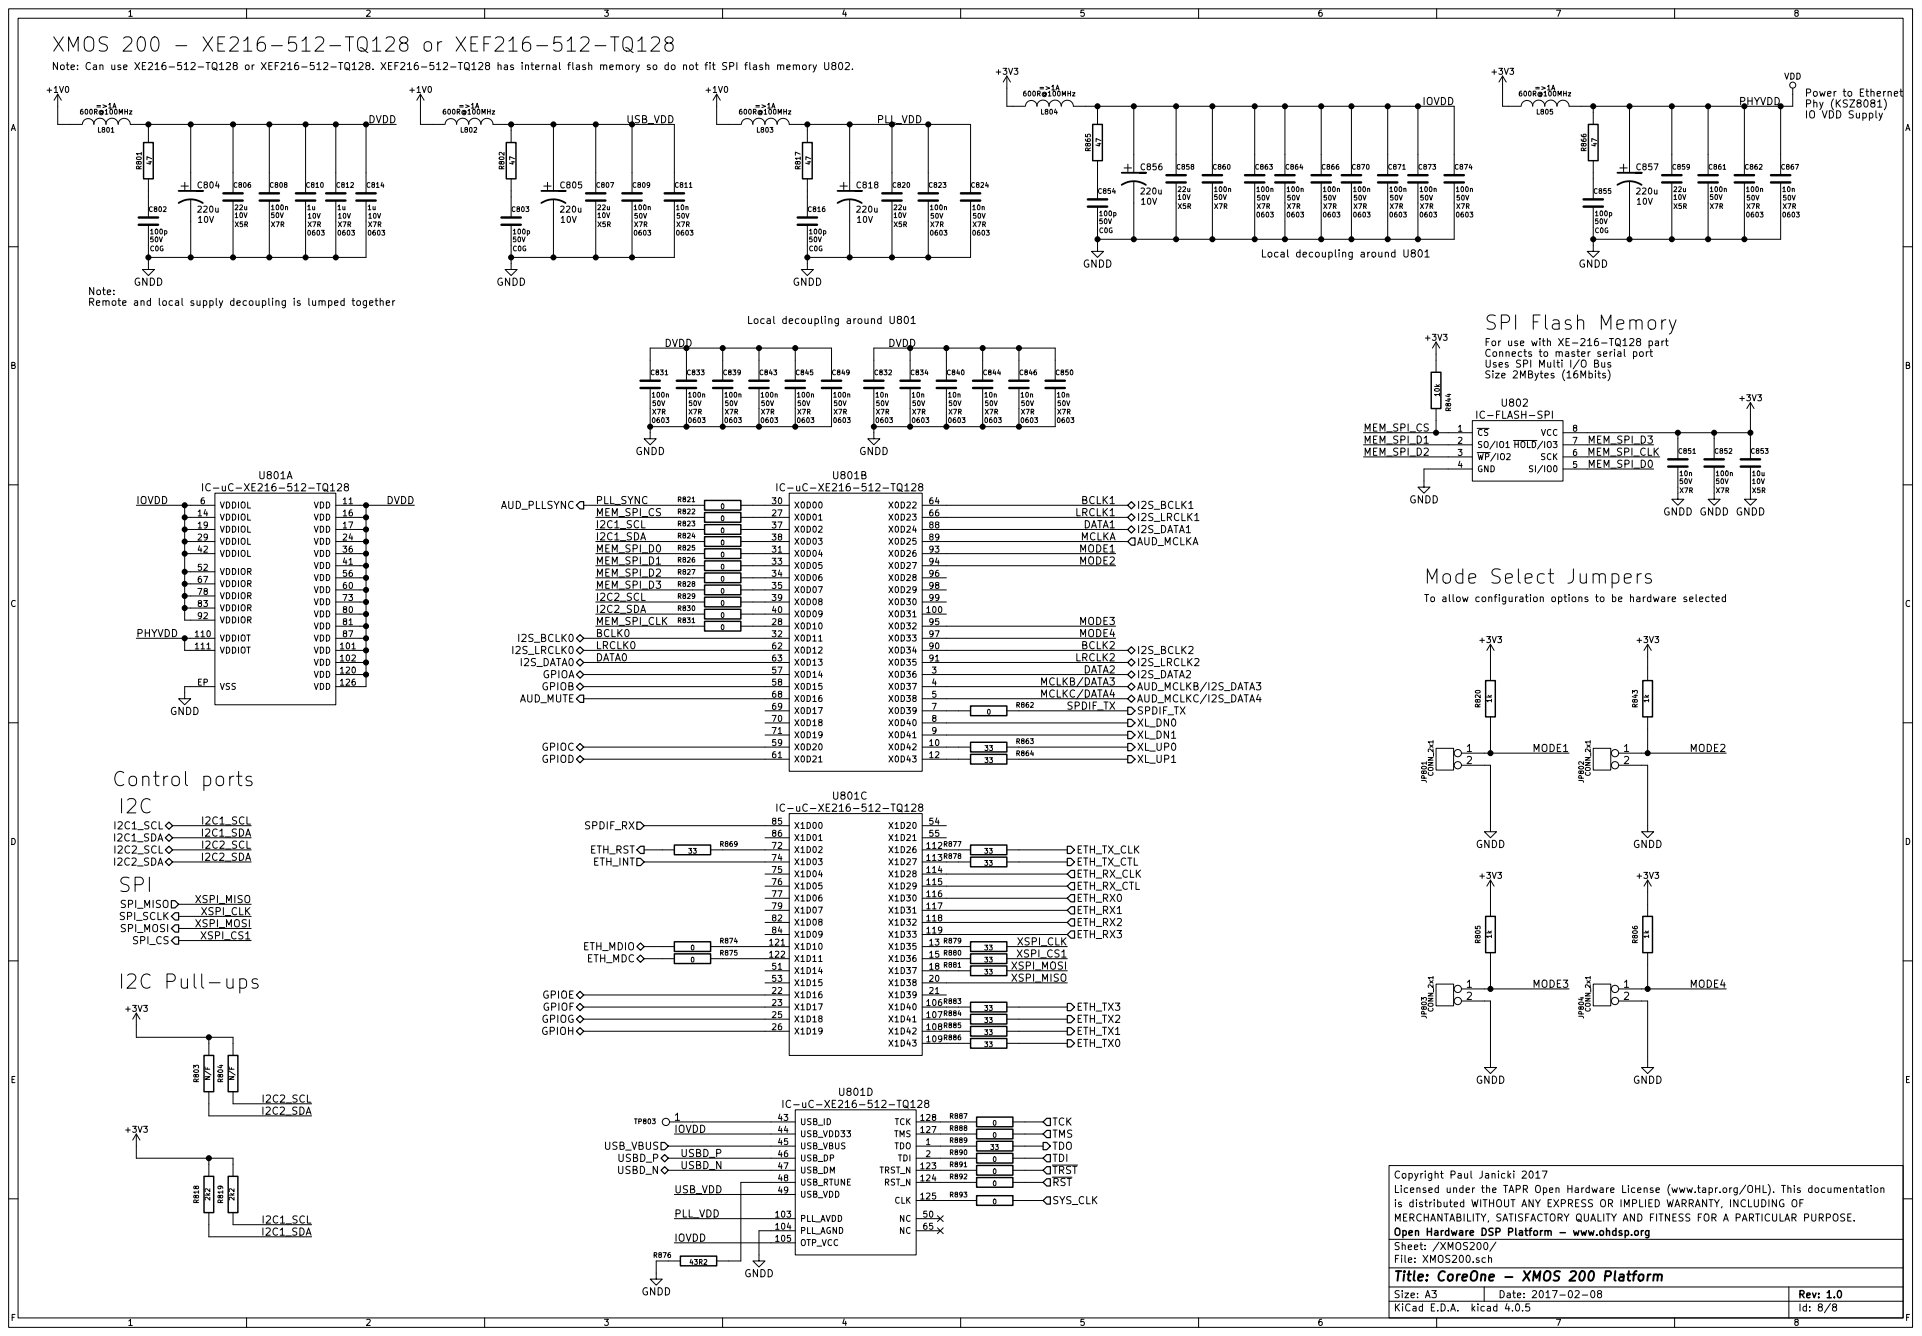
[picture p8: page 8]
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

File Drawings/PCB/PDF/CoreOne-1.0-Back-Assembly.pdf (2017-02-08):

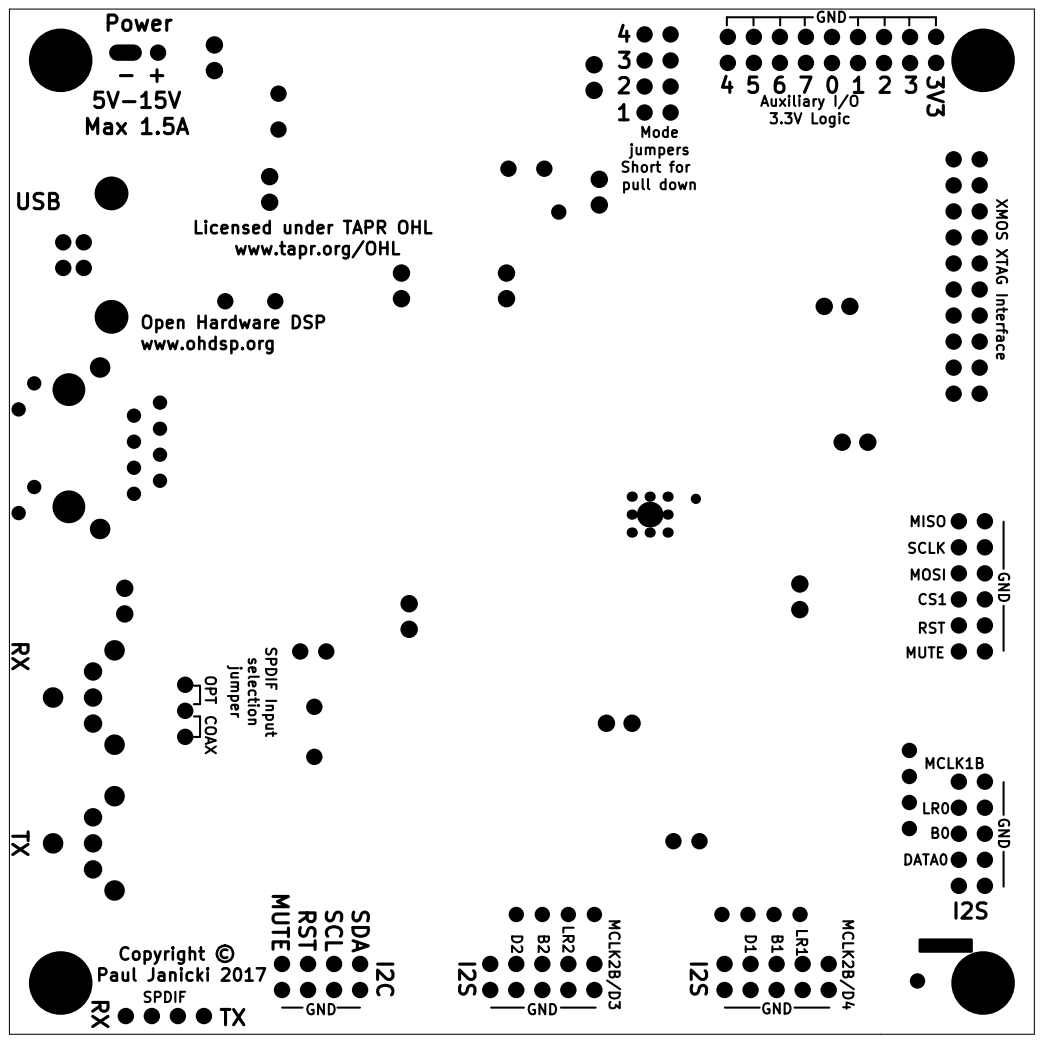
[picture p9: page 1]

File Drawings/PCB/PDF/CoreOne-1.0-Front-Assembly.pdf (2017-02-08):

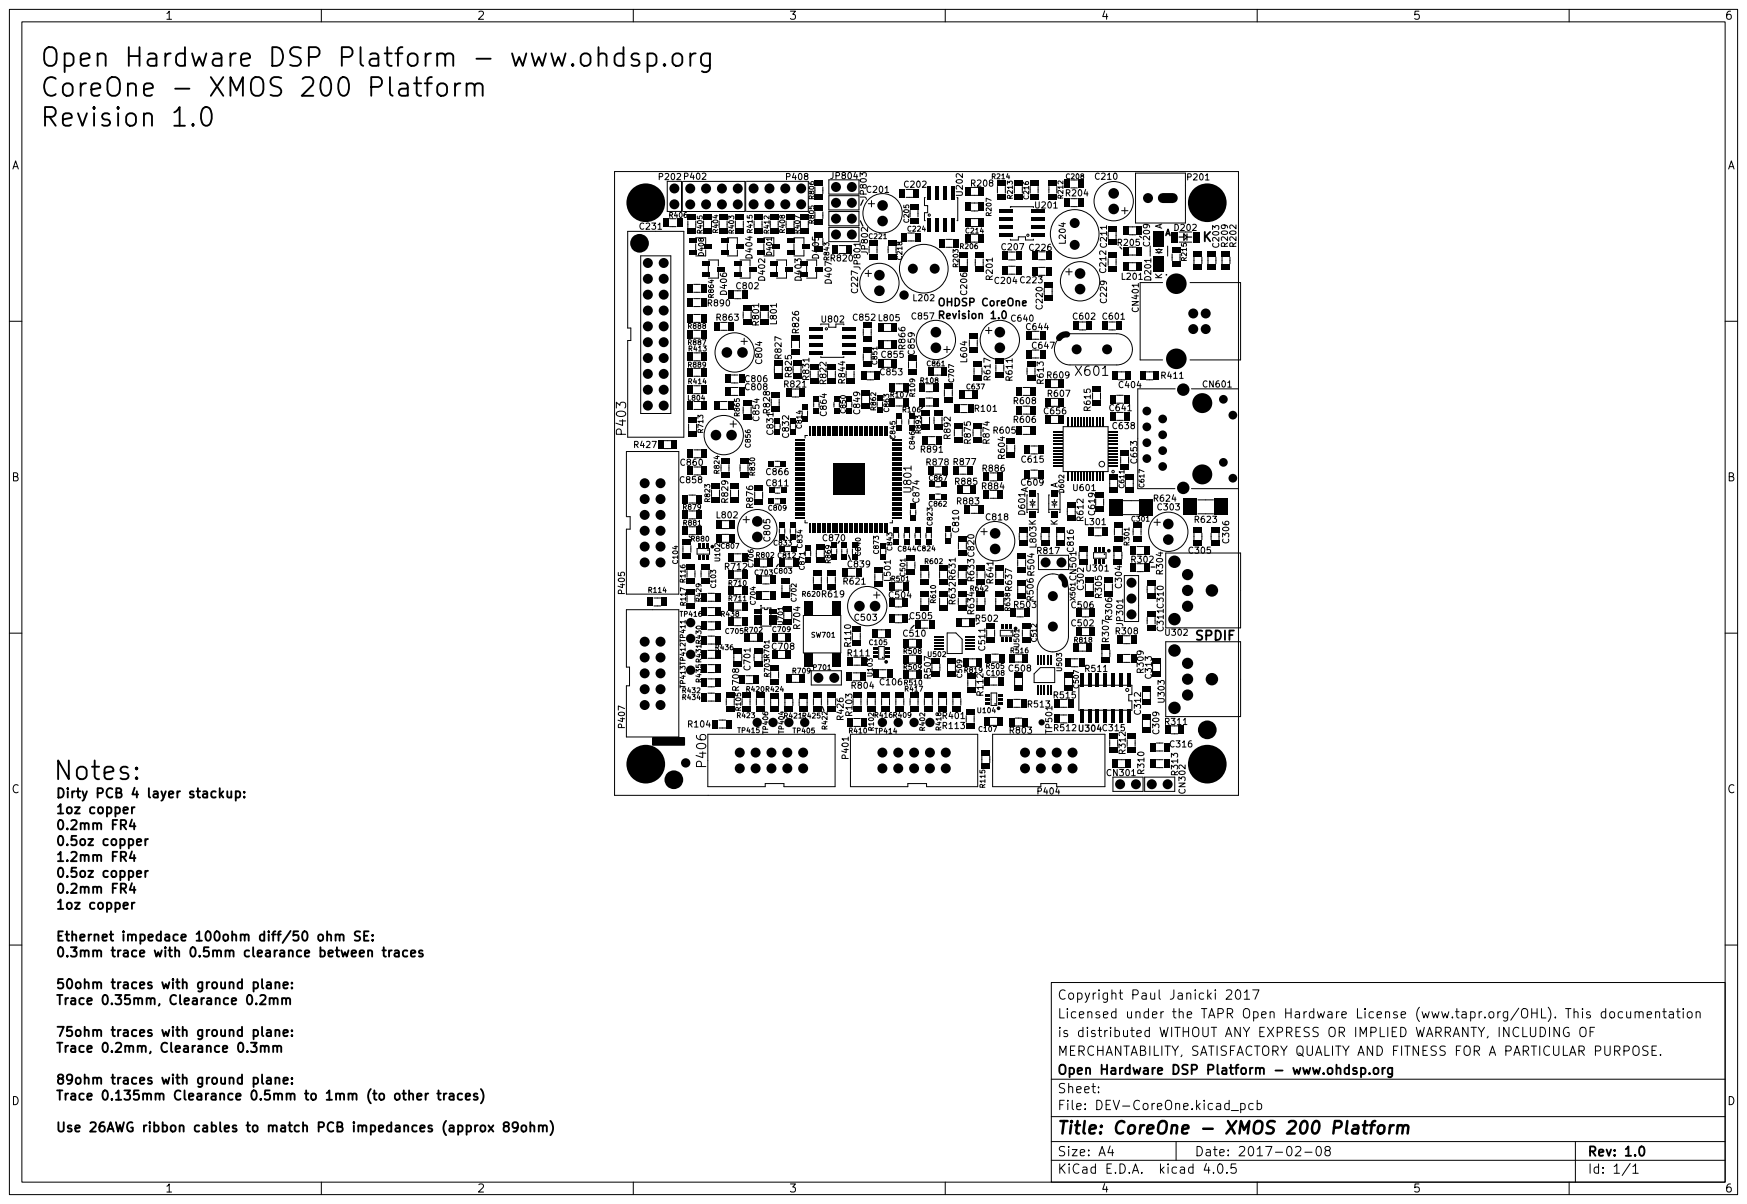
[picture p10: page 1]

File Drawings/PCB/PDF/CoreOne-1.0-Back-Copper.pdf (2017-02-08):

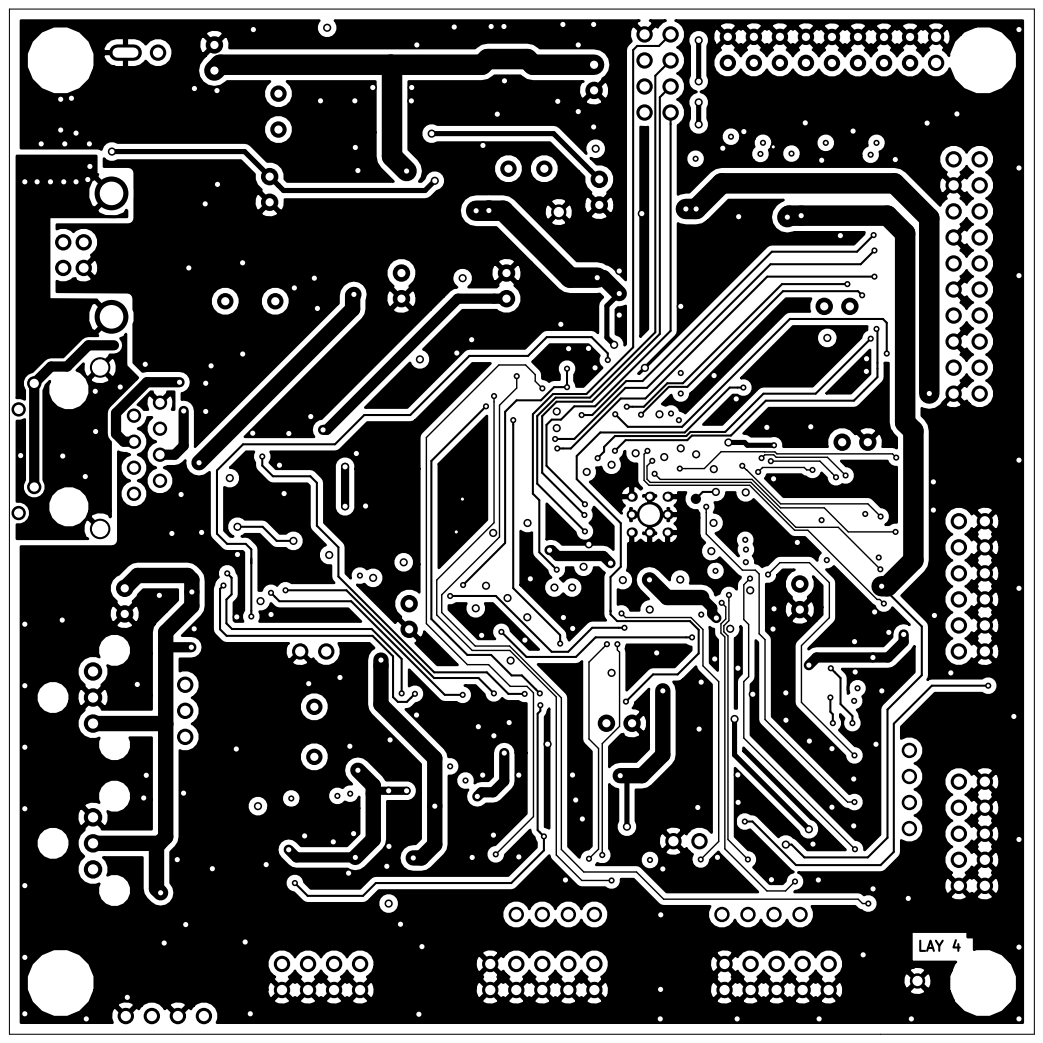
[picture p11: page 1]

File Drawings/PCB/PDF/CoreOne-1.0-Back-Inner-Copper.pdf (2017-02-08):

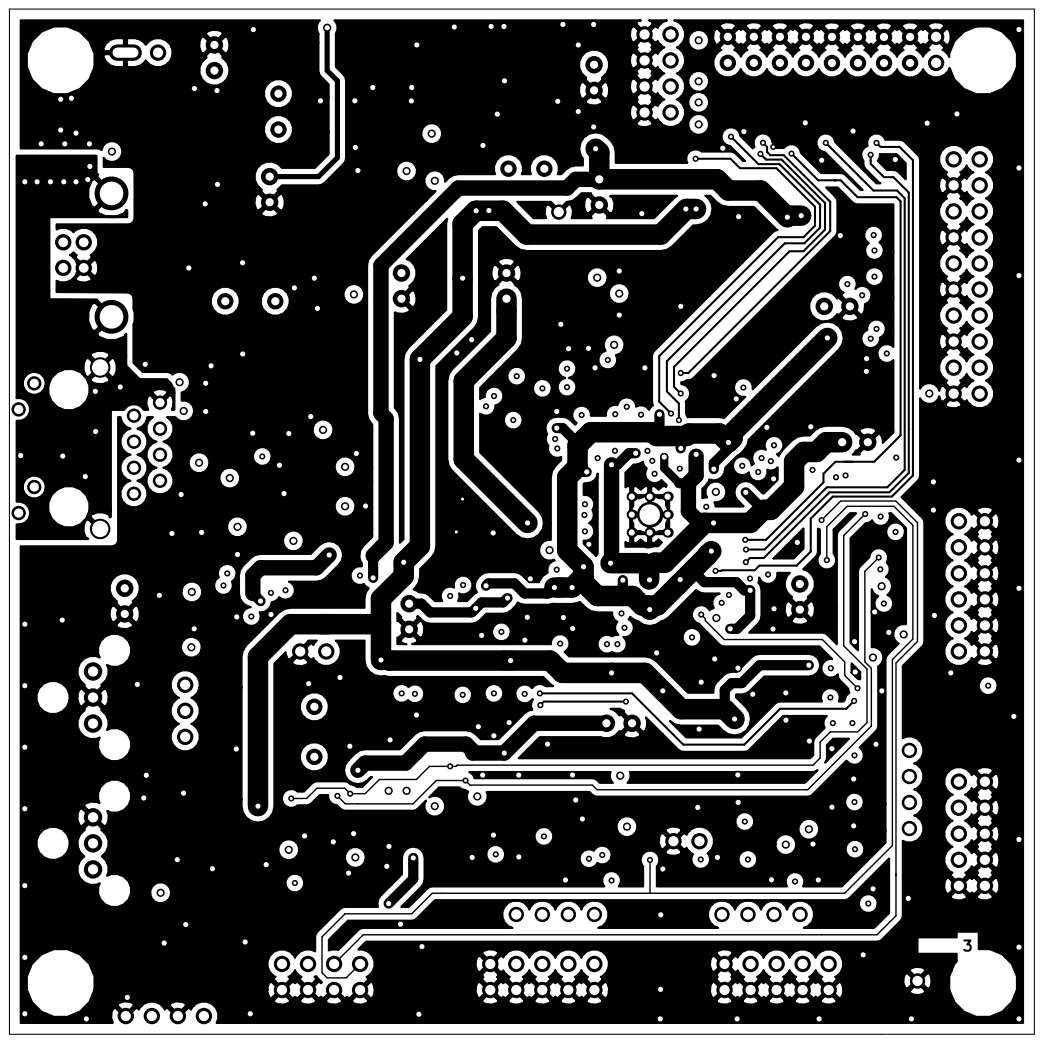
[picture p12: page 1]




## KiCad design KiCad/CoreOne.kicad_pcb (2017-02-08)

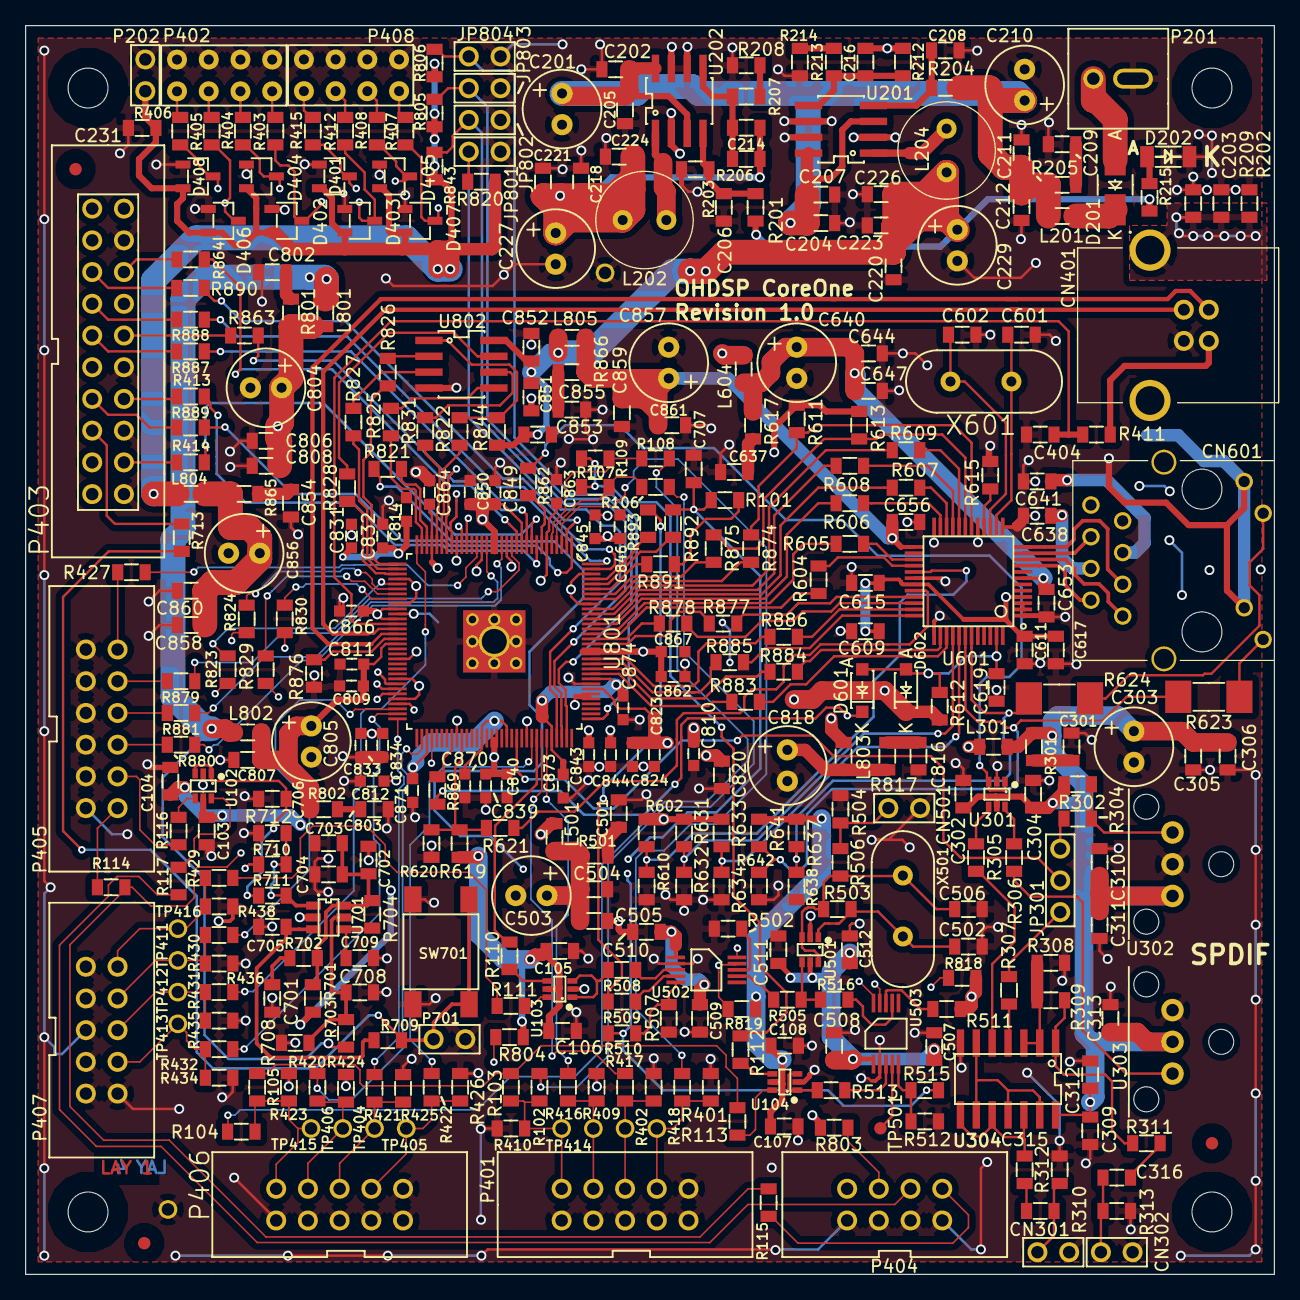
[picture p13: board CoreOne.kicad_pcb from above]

Board: 4 copper layers, 100.0 x 100.0 mm, 389 parts (1 on the bottom side), 245 nets.

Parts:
C103, C105, C107, C202, C204, C211, C218, C220, C221, C223, C305, C504, C644, C806, C807, C820, C858, C859: 22u; SMD-0805
C104, C106, C108, C203, C205, C206, C207, C208, C212, C224, C226, C231, C304, C306, C311, C312, C313, C315, C316, C404, C505, C508, C510, C512, C615, C617, C638, C641, C647, C653, C656, C703, C706, C707, C808, C852, C860, C861: 100n; SMD-0805
C201, C210, C227, C229, C303, C503, C640, C804, C805, C818, C856, C857: 220u; CAP-TH-D6.3mmP2.5mm
C209, C301, C501, C637, C701, C802, C803, C816, C854, C855: 100p; SMD-0805
C214, C216, C709: N/F; SMD-0805
C302, C309, C310, C507, C509, C511, C619, C702, C853: 10u; SMD-0805
C502, C506, C601, C602: 33p; SMD-0805
C609, C611: 1u; SMD-0805
C704, C705, C708, C851: 10n; SMD-0805
C809, C823, C831, C833, C839, C843, C845, C849, C862, C863, C864, C866, C870, C871, C873, C874: 100n; SMD-0603
C810, C812, C814: 1u; SMD-0603
C811, C824, C832, C834, C840, C844, C846, C850, C867: 10n; SMD-0603
CN301, CN302, CN501: COAX; CONN_SIL_2_1MM
CN401: CONN-USB-B-61729; CONN-USB-B-61729-0010
CN601: CONN_RJ45_ARJC02-111xxxx; CONN-RJ45-ARJC02-111xxxx
D201: B240A; DIODE-SMA
D202: Green LED 1206; SMD-1206
D401, D402, D403, D404, D405, D406, D407, D408: BAV99; IC-SOT23
D601, D602: SS14L; DIODE-SOD-123
FID201, FID202, FID203: MNT_HOLE; FID-1MM-3MM
JP301: CONN_3x1; CONN_SIL_3_1MM
JP801, JP802, JP803, JP804: CONN_2x1; CONN_SIL_2_1MM
L201, L301, L501, L604, L801, L802, L803, L804, L805: 600R@100MHz; SMD-0805
L202: DR0608-332L; IND-TH-DR0608
L204: DR0608-153L; IND-TH-DR0608
MNT201, MNT202, MNT203, MNT204: MNT_HOLE; MNT_HOLE_3.2mm
P201: CONN_2x1; CONN-2WAY-2.54mm-3.81mm-SPACING
P202, P701: CONN_2x1; CONN_SIL_2_1MM
P401, P406, P407: CONN_02X05; CONN_DIL_2X5_BOX_1MM
P402, P408: CONN_02X04; CONN_DIL_2X04
P403: CONN_02X10; CONN_DIL_2X10_BOX_1MM
P404: CONN_02X04; CONN_DIL_2X4_BOX_1MM
P405: CONN_02X06; CONN_DIL_2X6_BOX_1MM
R101, R102, R104, R106, R108, R208, R214, R413, R414, R416, R417, R418, R420, R421, R422, R427, R429, R713, R821, R822, R823, R824, R825, R826, R827, R828, R829, R830, R831, R862, R874, R875, R887, R888, R890, R891, R892, R893: 0; SMD-0805
R103, R105, R107, R109, R401, R402, R409, R410, R423, R424, R425, R426, R434, R435, R436, R438, R504, R506, R510, R515, R602, R620, R631, R633, R638, R642, R803, R804: N/F; SMD-0805
R110, R111, R112, R113, R114, R115, R116, R117, R604, R605, R606, R607, R608, R609, R621, R863, R864, R869, R877, R878, R879, R880, R881, R883, R884, R885, R886, R889: 33; SMD-0805
R201, R204, R403, R404, R405, R406, R407, R408, R412, R415, R502, R511, R610, R611, R613, R619, R632, R634, R805, R806, R820, R843: 1k; SMD-0805
R202, R209: 10; SMD-0805
R203: 750; SMD-0805
R205, R301, R501, R617, R702, R801, R802, R817, R865, R866: 47; SMD-0805
R206: 8k25; SMD-0805
R207: 33k; SMD-0805
R212: 36k; SMD-0805
R213: 11k5; SMD-0805
R215: 220; SMD-0805
R302, R308, R309, R612, R703, R844: 10k; SMD-0805
R304, R305, R306, R307, R313, R430, R431, R432: 75; SMD-0805
R310: 360; SMD-0805
R311, R709, R710, R711: 100; SMD-0805
R312: 91; SMD-0805
R411, R701: 1; SMD-0805
R503: 1Meg; SMD-0805
R505, R508, R509, R513, R516: 33R; SMD-0805
R507, R512: 0R; SMD-0805
R615: 6K49; SMD-0805
R623, R624: 220; SMD_MELF_0207
R637, R641: 4k7; SMD-0805
R704, R712: 100k; SMD-0805
R708: 7k5; SMD-0805
R818, R819: 2k2; SMD-0805
R876: 43R2; SMD-0805
SW701: SWITCH; SW_TACT_SMD
TP401, TP402, TP403, TP404, TP405, TP406, TP407, TP408, TP411, TP412, TP413, TP414, TP415, TP416: PIN; TP-TH-1mm
TP501, TP803: PIN; TP-1mm
U102, U103, U104, U301: NC7WZ16P6X; IC-SC70-6
U201, U202: IC-REG-ST1S40IDR; IC_SOIC_8
U302: IC-SPDIF-RX-OPTO; IC_SPDIF_OPTO
U303: IC-SPDIF-TX-OPTO; IC_SPDIF_OPTO
U304: 74HC04; IC_SOIC_14
U501: NC7WZ04P6X; IC-SC70-6
U502: CS2200-CP; IC-MSOP-10
U503: CS2100-CP; IC-MSOP-10
U601: KSZ8081MLX; IC-LQFP48_7x7
U701: TPS3808; IC-SOT23-6
U801: IC-uC-XE216-512-TQ128; IC-TQ128-XMOS-HF
U802: IC-FLASH-SPI; IC_SOIC_8
X501: 24M000; XTAL_HC49_TH
X601: 25M000; XTAL_HC49_TH

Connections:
+1V0: C214.1, C218.1, C221.1, C224.1, C227.1, L202.2, L801.1, L802.1, L803.1, R206.2, R703.1
+3V3: C103.1, C104.1, C105.1, C106.1, C107.1, C108.1, C216.1, C220.1, C223.1, C226.1, C229.1, C231.1, C851.1, C852.1, C853.1, D401.2, D402.2, D403.2, D404.2, D405.2, D406.2, D407.2, D408.2, D602.2, L204.2, L301.1, L501.1, L604.1, L804.1, L805.1, P202.1, R201.2, R212.2, R215.1, R511.1, R602.1, R611.1, R612.1, R613.1, R619.1, R631.1, R633.1, R637.1, R641.1, R701.2, R803.1, R804.1, R805.1, R806.1, R818.1, R819.1, R820.1, R843.1, R844.1, U102.5, U103.5, U104.5, U802.8
/AUD_CLK1: R508.1, U103.1, U103.3
/AUD_CLK2: R513.1, U104.1, U104.3
/AUD_MCLK1A: R110.1, U801.89
/AUD_MCLK1B: R111.1, R429.1
/AUD_MCLK2A: R107.1, R109.1, R112.1
/AUD_MCLK2B: R103.1, R105.1, R113.1
/AUD_MUTE: R114.2, R115.2, U801.68
/AUD_PLLSYNC: R510.1, R515.1, R821.1
/AUX_DIGI0: D402.3, R403.2, U801.57
/AUX_DIGI1: D404.3, R404.2, U801.58
/AUX_DIGI2: D406.3, R405.2, U801.59
/AUX_DIGI3: D408.3, R406.2, U801.61
/AUX_DIGI4: D407.3, R407.2, U801.22
/AUX_DIGI5: D405.3, R408.2, U801.23
/AUX_DIGI6: D403.3, R412.2, U801.25
/AUX_DIGI7: D401.3, R415.2, U801.26
/Clock-CS2200/24M_CLK_1: R505.1, U502.7
/Clock-CS2200/24M_CLK_2: R516.1, U503.7
/Clock-CS2200/CS_3V3: C503.1, C504.1, C505.1, C507.1, C508.1, C509.1, C510.1, C511.1, C512.1, L501.2, R501.1, U501.5, U502.1, U503.1
/Connectors/I2S_MCLKB/D4: P406.2, R104.2, R105.2, R423.2, TP415.1
/Connectors/I2S_MCLKC/D3: P401.2, R102.2, R103.2, R410.2, TP414.1
/ETH_INT: R619.2, R620.1, R621.1, U801.74
/ETH_MDC: R613.2, R875.2, U601.19
/ETH_MDIO: R611.2, R874.2, U601.18
/ETH_RST: D601.2, R869.2
/ETH_RX0: R606.2, U801.116
/ETH_RX1: R607.2, U801.117
/ETH_RX2: R608.2, U801.118
/ETH_RX3: R609.2, U801.119
/ETH_RX_CLK: R604.2, U801.114
/ETH_RX_CTL: R605.2, U801.115
/ETH_TX0: R886.2, U601.35
/ETH_TX1: R885.2, U601.36
/ETH_TX2: R884.2, U601.38
/ETH_TX3: R883.2, U601.39
/ETH_TX_CLK: R877.2, U601.33
/ETH_TX_CTL: R878.2, U601.34
/Eth-KSZ8081/A3V3: C640.1, C644.1, C647.1, C653.1, L604.2, R617.1, U601.7
/Eth-KSZ8081/CONFIG0: R631.2, R632.1, U601.40
/Eth-KSZ8081/CONFIG1: R633.2, R634.1, U601.41
/Eth-KSZ8081/D1V2: C609.1, C611.1, C615.1, C617.1, U601.4, U601.31
/Eth-KSZ8081/ISO: R602.2, R610.1, U601.29
/Eth-KSZ8081/KSZ_RST: C619.1, D601.1, D602.1, R612.2, U601.47
/Eth-KSZ8081/NWAYEN: R623.2, R641.2, R642.1, U601.42
/Eth-KSZ8081/RX_N: CN601.2, U601.9
/Eth-KSZ8081/RX_P: CN601.1, U601.10
/Eth-KSZ8081/SPEED: R624.2, R637.2, R638.1, U601.43
/Eth-KSZ8081/TX_N: CN601.6, U601.11
/Eth-KSZ8081/TX_P: CN601.3, U601.12
/GEN_RST: C706.1, R711.1, U102.1, U102.3
/I2C1_SCL: R819.2, R823.1, U502.9, U503.9
/I2C1_SDA: R818.2, R824.1, U502.10, U503.10
/I2C2_SCL: P404.4, R803.2, R830.1
/I2C2_SDA: P404.2, R804.2, R829.1
/I2C_MUTE: P404.8, R115.1
/I2C_RST: P404.6, R117.1
/I2S_BCLK0: R431.1, U801.32
/I2S_BCLK1: R421.2, U801.64
/I2S_BCLK2: R417.2, U801.90
/I2S_D3: R102.1, R106.1
/I2S_D4: R104.1, R108.1
/I2S_LRCLK0: R430.1, U801.62
/I2S_LRCLK1: R420.2, U801.66
/I2S_LRCLK2: R416.2, U801.91
/I2S_SDATA0: R432.1, U801.63
/I2S_SDATA1: R422.2, U801.88
/I2S_SDATA2: R418.2, U801.3
/SPDIF_RX: JP301.2, U801.85
/SPDIF_TX: R862.1, U301.1, U301.3
/SPI_CS1: P405.8, R880.2
/SPI_MISO: R427.2, U801.20
/SPI_MOSI: P405.6, R881.2
/SPI_MUTE: P405.12, R114.1
/SPI_RST: P405.10, R116.1
/SPI_SCLK: P405.4, R879.2
/SYS_CLK: R509.1, R893.2
/TCK: P403.9, R887.2
/TDI: P403.5, R890.2
/TDO: P403.13, R889.2
/TMS: P403.7, R888.2
/USBD_N: CN401.2, U801.47
/USBD_P: CN401.3, U801.46
/USB_VBUS: C404.2, R411.2, U801.45
/XL_DN0: R413.2, U801.8
/XL_DN1: R414.2, U801.9
/XL_UP0: P403.10, R863.1
/XL_UP1: P403.6, R864.1
/XMOS200/AUD_MCLKB/I2S_DATA3: R106.2, R107.2, U801.4
/XMOS200/AUD_MCLKC/I2S_DATA4: R108.2, R109.2, U801.5
/XMOS200/DVDD: C804.1, C806.1, C808.1, C810.1, C812.1, C814.1, C831.1, C832.1, C833.1, C834.1, C839.1, C840.1, C843.1, C844.1, C845.1, C846.1, C849.1, C850.1, L801.2, R801.1, U801.11, U801.16, U801.17, U801.24, U801.36, U801.41, U801.56, U801.60, U801.73, U801.80, U801.81, U801.87, U801.101, U801.102, U801.120, U801.126
/XMOS200/IOVDD: C856.1, C858.1, C860.1, C863.1, C864.1, C866.1, C870.1, C871.1, C873.1, C874.1, L804.2, R865.1, U801.6, U801.14, U801.19, U801.29, U801.42, U801.44, U801.52, U801.67, U801.78, U801.83, U801.92, U801.105
/XMOS200/MEM_SPI_CLK: R831.1, U802.6
/XMOS200/MEM_SPI_CS: R822.1, R844.2, U802.1
/XMOS200/MEM_SPI_D0: R825.1, U802.5
/XMOS200/MEM_SPI_D1: R826.1, U802.2
/XMOS200/MEM_SPI_D2: R827.1, U802.3
/XMOS200/MEM_SPI_D3: R828.1, U802.7
/XMOS200/MODE1: JP801.1, R820.2, U801.93
/XMOS200/MODE2: JP802.1, R843.2, U801.94
/XMOS200/MODE3: JP803.1, R805.2, U801.95
/XMOS200/MODE4: JP804.1, R806.2, U801.97
/XMOS200/PLL_VDD: C818.1, C820.1, C823.1, C824.1, L803.2, R817.1, U801.103
/XMOS200/USB_VDD: C805.1, C807.1, C809.1, C811.1, L802.2, R802.1, U801.49
/XMOS200/~TRST~: R101.1, R891.2
/XMOS_RST: C707.1, R101.2, R710.1, R892.2
/XSYS_RST: P403.15, R713.2
GNDD: C103.2, C104.2, C105.2, C106.2, C107.2, C108.2, C201.2, C202.1, C203.1, C204.1, C205.1, C206.1, C207.1, C208.1, C209.2, C210.2, C211.1, C212.1, C218.2, C220.2, C221.2, C223.2, C224.2, C226.2, C227.2, C229.2, C231.2, C301.2, C302.2, C303.2, C304.2, C305.2, C306.2, C309.2, C310.2, C311.2, C312.2, C313.2, C404.1, C501.2, C502.2, C503.2, C504.2, C505.2, C506.2, C507.2, C508.2, C509.2, C510.2, C511.2, C512.2, C601.2, C602.2, C609.2, C611.2, C615.2, C617.2, C619.2, C637.2, C638.2, C640.2, C641.2, C644.2, C647.2, C653.2, C656.2, C701.2, C702.2, C703.2, C704.2, C705.2, C706.2, C707.2, C708.2, C709.2, C802.2, C803.2, C804.2, C805.2, C806.2, C807.2, C808.2, C809.2, C810.2, C811.2, C812.2, C814.2, C816.2, C818.2, C820.2, C823.2, C824.2, C831.2, C832.2, C833.2, C834.2, C839.2, C840.2, C843.2, C844.2, C845.2, C846.2, C849.2, C850.2, C851.2, C852.2, C853.2, C854.2, C855.2, C856.2, C857.2, C858.2, C859.2, C860.2, C861.2, C862.2, C863.2, C864.2, C866.2, C867.2, C870.2, C871.2, C873.2, C874.2, CN301.2, CN302.2, CN401.4, CN501.2, CN601.10, CN601.12, D202.2, D401.1, D402.1, D403.1, D404.1, D405.1, D406.1, D407.1, D408.1, JP801.2, JP802.2, JP803.2, JP804.2, P201.2, P202.2, P401.1, P401.3, P401.5, P401.7, P401.9, P401.10, P402.1, P402.3, P402.5, P402.7, P403.4, P403.8, P403.12, P403.16, P403.20, P404.1, P404.3, P404.5, P404.7, P405.1, P405.3, P405.5, P405.7, P405.9, P405.11, P406.1, P406.3, P406.5, P406.7, P406.9, P406.10, P407.1, P407.3, P407.5, P407.7, P407.9, P407.10, P408.1, P408.3, P408.5, P408.7, P701.2, R202.2, R203.1, R208.1, R209.2, R214.1, R308.1, R312.1, R313.1, R401.1, R402.1, R409.1, R410.1, R423.1, R424.1, R425.1, R426.1, R434.1, R435.1, R436.1, R438.1, R502.2, R504.1, R507.2, R512.2, R610.2, R615.2, R620.2, R632.2, R634.2, R638.2, R642.2, R708.1, R712.1, R876.1, SW701.2, TP407.1, TP408.1, U102.2, U103.2, U104.2, U201.2, U201.6, U201.7, U202.2, U202.6, U202.7, U301.2, U302.2, U303.3, U304.7, U501.2, U502.2, U503.2, U601.1, U601.2, U601.3, U601.13, U601.17, U601.24, U601.30, U601.37, U701.2, U801.104, U801.EP, U802.4
GNDPWR: C203.2, CN401.5, CN601.8, CN601.13, R202.1, R209.1
unnamed: C206.2, R201.1, R203.2, U202.4
unnamed: C208.2, R204.1, U201.4
unnamed: C209.1, R205.2
unnamed: C214.2, R206.1, R207.2, U202.5
unnamed: C216.2, R212.1, R213.2, U201.5
unnamed: C301.1, R301.2
unnamed: C302.1, C303.1, C304.1, C305.1, C306.1, C309.1, C310.1, C311.1, C312.1, C313.1, L301.2, R301.1, R302.1, U301.5, U302.1, U303.2, U304.14
unnamed: C315.1, R310.2
unnamed: C315.2, U304.8, U304.10, U304.12
unnamed: C316.1, R311.2
unnamed: C316.2, CN302.1, R313.2
unnamed: C501.1, R501.2
unnamed: C502.1, R503.2, U501.1, X501.1
unnamed: C506.1, R503.1, R506.2, U501.3, U501.6, X501.2
unnamed: C601.1, U601.14, X601.1
unnamed: C602.1, U601.15, X601.2
unnamed: C637.1, R617.2
unnamed: C638.1, CN601.4
unnamed: C641.1, CN601.5
unnamed: C701.1, R702.2
unnamed: C702.1, C703.1, C704.1, R701.1, R702.1, R704.1, U701.6
unnamed: C705.1, R709.1, U701.3
unnamed: C708.1, R703.2, R708.2, U701.5
unnamed: C709.1, R704.2, U701.4
unnamed: C802.1, R801.2
unnamed: C803.1, R802.2
unnamed: C816.1, R817.2
unnamed: C854.1, R865.2
unnamed: C855.1, R866.2
unnamed: CN301.1, R310.1, R312.2
unnamed: CN401.1, R411.1
unnamed: CN501.1, R504.2, R506.1
unnamed: CN601.9, R623.1
unnamed: CN601.11, R624.1
unnamed: D201.1, P201.1
unnamed: D201.2, L201.1
unnamed: D202.1, R215.2
unnamed: JP301.1, R304.1
unnamed: JP301.3, R307.2
unnamed: L202.1, U202.1
unnamed: L204.1, U201.1
unnamed: P401.4, R409.2, R416.1, TP401.1
unnamed: P401.6, R402.2, R417.1, TP402.1
unnamed: P401.8, R401.2, R418.1, TP403.1
unnamed: P402.2, R403.1
unnamed: P402.4, R404.1
unnamed: P402.6, R405.1
unnamed: P402.8, R406.1
unnamed: P403.14, R413.1
unnamed: P403.18, R414.1
unnamed: P405.2, R427.1
unnamed: P406.4, R420.1, R424.2, TP406.1
unnamed: P406.6, R421.1, R425.2, TP404.1
unnamed: P406.8, R422.1, R426.2, TP405.1
unnamed: P407.2, R429.2, R438.2, TP416.1
unnamed: P407.4, R430.2, R436.2, TP411.1
unnamed: P407.6, R431.2, R435.2, TP412.1
unnamed: P407.8, R432.2, R434.2, TP413.1
unnamed: P408.2, R407.1
unnamed: P408.4, R408.1
unnamed: P408.6, R412.1
unnamed: P408.8, R415.1
unnamed: P701.1, R709.2, R713.1, SW701.1
unnamed: R110.2, U103.4
unnamed: R111.2, U103.6
unnamed: R112.2, U104.4
unnamed: R113.2, U104.6
unnamed: R116.2, U102.4
unnamed: R117.2, U102.6
unnamed: R207.1, R208.2
unnamed: R213.1, R214.2
unnamed: R302.2, R304.2, U302.3
unnamed: R305.1, U304.5
unnamed: R305.2, U301.4
unnamed: R306.1, U301.6
unnamed: R306.2, U303.1
unnamed: R307.1, U304.4
unnamed: R308.2, R309.1, U304.2, U304.3
unnamed: R309.2, R311.1, U304.1
unnamed: R502.1, U502.8
unnamed: R505.2, R516.2, U501.4
unnamed: R507.1, R510.2, U502.5
unnamed: R508.2, U502.3
unnamed: R509.2, U502.4
unnamed: R511.2, U503.8
unnamed: R512.1, R515.2, U503.5
unnamed: R513.2, U503.3
unnamed: R604.1, U601.28
unnamed: R605.1, U601.27
unnamed: R606.1, U601.23
unnamed: R607.1, U601.22
unnamed: R608.1, U601.21
unnamed: R609.1, U601.20
unnamed: R615.1, U601.16
unnamed: R621.2, U601.32
unnamed: R710.2, R711.2, R712.2, U701.1
unnamed: R821.2, U801.30
unnamed: R822.2, U801.27
unnamed: R823.2, U801.37
unnamed: R824.2, U801.38
unnamed: R825.2, U801.31
unnamed: R826.2, U801.33
unnamed: R827.2, U801.34
unnamed: R828.2, U801.35
unnamed: R829.2, U801.39
unnamed: R830.2, U801.40
unnamed: R831.2, U801.28
unnamed: R862.2, U801.7
unnamed: R863.2, U801.10
unnamed: R864.2, U801.12
unnamed: R869.1, U801.72
unnamed: R874.1, U801.121
unnamed: R875.1, U801.122
unnamed: R876.2, U801.48
unnamed: R877.1, U801.112
unnamed: R878.1, U801.113
unnamed: R879.1, U801.13
unnamed: R880.1, U801.15
unnamed: R881.1, U801.18
unnamed: R883.1, U801.106
unnamed: R884.1, U801.107
unnamed: R885.1, U801.108
unnamed: R886.1, U801.109
unnamed: R887.1, U801.128
unnamed: R888.1, U801.127
unnamed: R889.1, U801.1
unnamed: R890.1, U801.2
unnamed: R891.1, U801.123
unnamed: R892.1, U801.124
unnamed: R893.1, U801.125
unnamed: TP501.1, U503.4
unnamed: TP803.1, U801.43
unnamed: U304.6, U304.9, U304.11, U304.13
VCC: C201.1, C202.2, C204.2, C205.2, C207.2, C210.1, C211.2, C212.2, L201.2, R204.2, R205.1, U201.3, U201.8, U202.3, U202.8
VDD: C656.1, C857.1, C859.1, C861.1, C862.1, C867.1, L805.2, R866.1, U601.25, U801.110, U801.111

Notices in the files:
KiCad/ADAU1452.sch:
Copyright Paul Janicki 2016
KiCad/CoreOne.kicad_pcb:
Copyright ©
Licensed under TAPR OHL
